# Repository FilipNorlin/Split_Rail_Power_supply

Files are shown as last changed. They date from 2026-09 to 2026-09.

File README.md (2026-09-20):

# PFC

# General Continuous-Time State-Space Form

$$
\dot{\mathbf{x}}(t) = A\mathbf{x}(t) + B\mathbf{u}(t)
$$
$$
\mathbf{y}(t) = C\mathbf{x}(t) + D\mathbf{u}(t)
$$

---

$$
	\underbrace{ \left(
		\begin{matrix}
		\dot{x}_{1}(t) \\
		\dot{x}_{2}(t) \\
		\dots \\
		\dot{x}_{n}(t)
		\end{matrix}
	\right) }_{ \dot{x}(t) }
	=
	\underbrace{ \left(
	\begin{matrix}
	A_{11}, A_{12} \dots A_{1n} \\
	A_{21}, A_{22} \dots A_{2n} \\
	\dots \\
	A_{n1}, A_{n2} \dots A_{nn}
	\end{matrix}
	\right) }_{ A }
	\underbrace{ \left(
	\begin{matrix}
	x_{1}(t) \\
	x_{2}(t) \\
	\dots \\
	x_{n}(t)
	\end{matrix}
	\right) }_{ x(t) }
	+ 
	\underbrace{ \left(
	\begin{matrix}
	B_{1} \\
	B_{2} \\
	\dots \\
	B_{n}
	\end{matrix}
	\right) }_{ B }	
	u(t)
$$

$$
y(t) = \underbrace{ [C_{1}, C_{2},\dots C_{n}] }_{ C } 
\underbrace{ \left(
\begin{matrix}
x_{1}(t) \\
x_{2}(t) \\
\dots \\
x_{n}(t)
\end{matrix}
\right) }_{ x(t) }
+
Du(t)
$$

# State Variables

## Large Signal Model

$$
\begin{align}
	x &= 
	\begin{bmatrix}
	i_{L_{A}}(t) \\
	i_{L_{B}}(t) \\
	v_{\text{out}}(t)
	\end{bmatrix}
	& \dot{x} = 
	\begin{bmatrix}
	\dot{i}_{L_{A}}(t) \\
	\dot{i}_{L_{B}}(t) \\
	\dot{v}_{\text{out}}(t)
	\end{bmatrix}
	&& u=v_{\text{in}}
	&& y=v_{\text{out}}
\end{align}
$$

The two switches are $180\degree$ out of phase. This means that the system will have 4 different states of operation. There will be a point where $\text{q}_{\text{A}}$ will be high and $\text{q}_{B}$ low and vise versa, if $\text{D}>0.5$ there will also be a point where both $\text{q}_{\text{A}}$ and $\text{q}_{B}$ will be high simultaneously. If $D < 0.5$  there will be a point where $\text{q}_{\text{A}}$ and $\text{q}_{\text{B}}$ both will be low simultaneously. This makes 4 states:

#### State 1: $\text{q}_{\text{A}}$ & $\text{q}_{\text{B}}$ are high

$$
\begin{align}
v_{L_{A}}(t) &= L \frac{di_{\text{L}_{A}}(t)}{dt} \implies \frac{di_{\text{L}_{A}}(t)}{dt} = \frac{v_{\text{in}}(t)}{L} \\ \\
v_{L_{B}}(t) &= L \frac{di_{\text{L}_{B}}(t)}{dt} \implies \frac{di_{\text{L}_{B}}(t)}{dt} = \frac{v_{\text{in}}(t)}{L} \\ \\
i_{c}(t) &= C \frac{d v_{c}(t)}{dt} \implies \frac{d v_{c}(t)}{dt} = \frac{i_{c}(t)}{C} = -\frac{v_{\text{out}}(t)}{RC}
\end{align}
$$

Both switches are turned on thus both inductors are getting magnetized. The capacitor isnt being charged at this point by any inductor meaning that it is only being discharged to the load, hence why the current is negative.

#### State 2: $\text{q}_{\text{A}}$ high & $\text{q}_{\text{B}}$ low

$$
\begin{align}
v_{L_{A}}(t) &= L \frac{di_{\text{L}_{A}}(t)}{dt} \implies \frac{di_{\text{L}_{A}}(t)}{dt} = \frac{v_{\text{in}}(t)}{L} \\ \\
v_{L_{B}}(t) &= L \frac{di_{\text{L}_{B}}(t)}{dt} \implies \frac{di_{\text{L}_{B}}(t)}{dt} = \frac{v_{\text{in}}(t) - v_{\text{out}}(t)}{L} \\ \\
i_{c}(t) &= C \frac{d v_{c}(t)}{dt} \implies \frac{d v_{c}(t)}{dt} = \frac{i_{c}(t)}{C} = \frac{i_{\text{L}_{B}}(t)}{C} -\frac{v_{\text{out}}(t)}{RC}
\end{align}
$$

Inductor A is still getting magnetized while inductor B is getting demagnetized. The energy from inductor B is being used to charge the output capacitor. 

#### State 3: $\text{q}_{\text{A}}$ low & $\text{q}_{\text{B}}$ high

$$
\begin{align}
v_{L_{A}}(t) &= L \frac{di_{\text{L}_{A}}(t)}{dt} \implies \frac{di_{\text{L}_{A}}(t)}{dt} = \frac{v_{\text{in}}(t) - v_{\text{out}}(t)}{L} \\ \\
v_{L_{B}}(t) &= L \frac{di_{\text{L}_{B}}(t)}{dt} \implies \frac{di_{\text{L}_{B}}(t)}{dt} = \frac{v_{\text{in}}(t)}{L} \\ \\
i_{c}(t) &= C \frac{d v_{c}(t)}{dt} \implies \frac{d v_{c}(t)}{dt} = \frac{i_{c}(t)}{C} = \frac{i_{\text{L}_{A}}(t)}{C} -\frac{v_{\text{out}}(t)}{RC}
\end{align}
$$

Now Inductor B is getting magnetized while inductor A is getting demagnetized. The energy from inductor A is being used to charge the output capacitor. 

#### State 4: $\text{q}_{\text{A}}$ low & $\text{q}_{\text{B}}$ low

$$
\begin{align}
v_{L_{A}}(t) &= L \frac{di_{\text{L}_{A}}(t)}{dt} \implies \frac{di_{\text{L}_{A}}(t)}{dt} = \frac{v_{\text{in}}(t) - v_{\text{out}}(t)}{L} \\ \\
v_{L_{B}}(t) &= L \frac{di_{\text{L}_{B}}(t)}{dt} \implies \frac{di_{\text{L}_{B}}(t)}{dt} = \frac{v_{\text{in}}(t) - v_{\text{out}}(t)}{L} \\ \\
i_{c}(t) &= C \frac{d v_{c}(t)}{dt} \implies \frac{d v_{c}(t)}{dt} = \frac{i_{c}(t)}{C} = \frac{i_{\text{L}_{A}}(t) + i_{\text{L}_{B}}(t)}{C} -\frac{v_{\text{out}}(t)}{RC}
\end{align}
$$

In this last state both the switches are off meaning that both the inductors are getting demagnetized into the capacitor. Having two or more inductors switching with some offset will make the capacitor get charged more frequently thus reducing the voltage ripple on the output. 

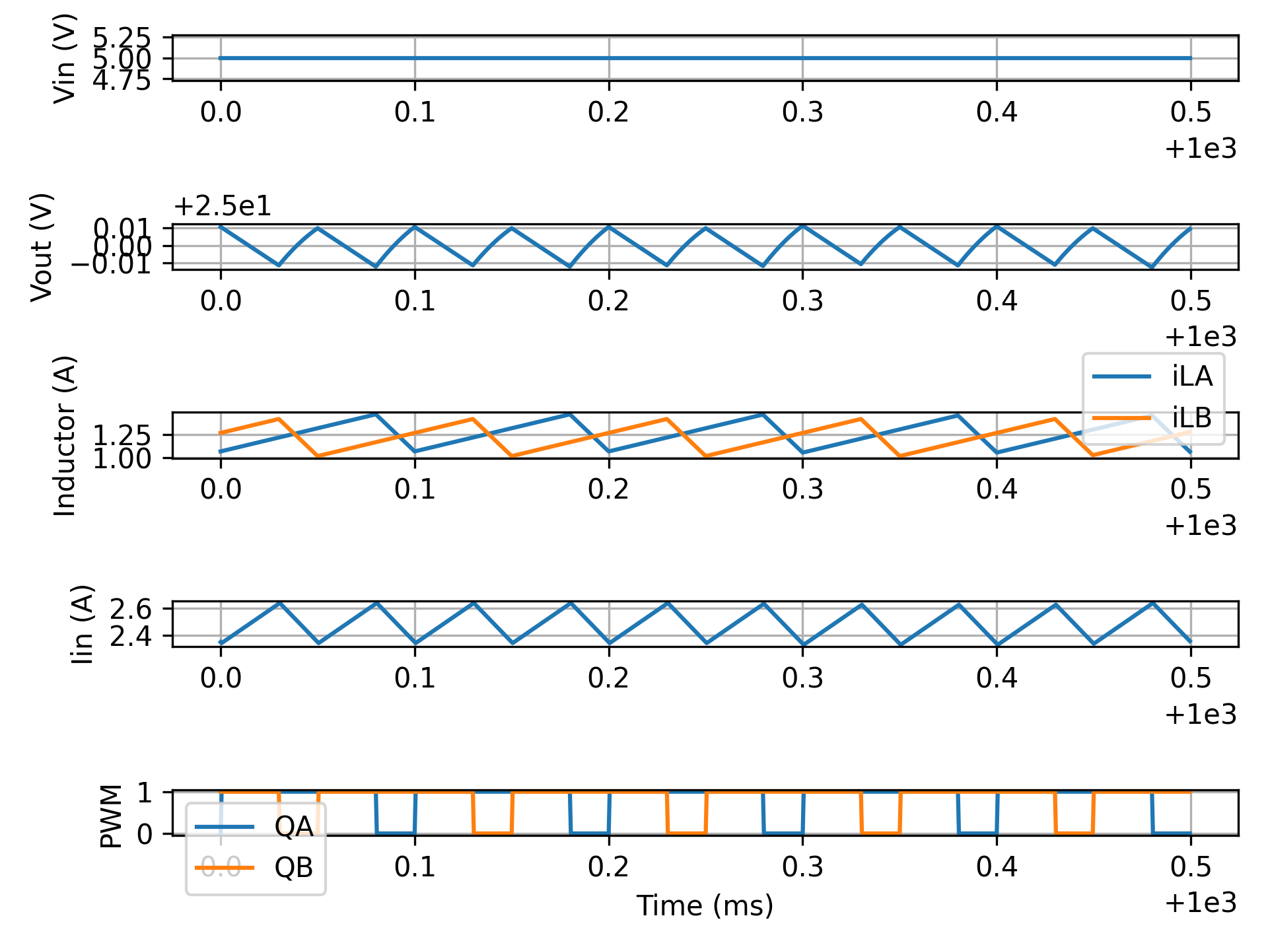
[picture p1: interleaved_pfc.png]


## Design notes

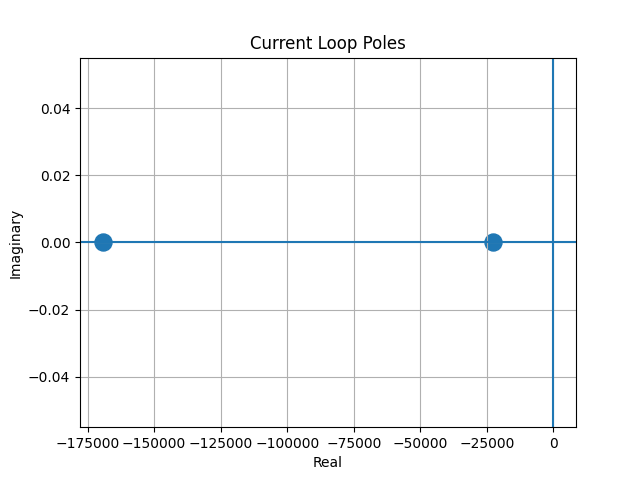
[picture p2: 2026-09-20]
Simulation/scirpts/dual_converter/Current_Loop_Poles.png

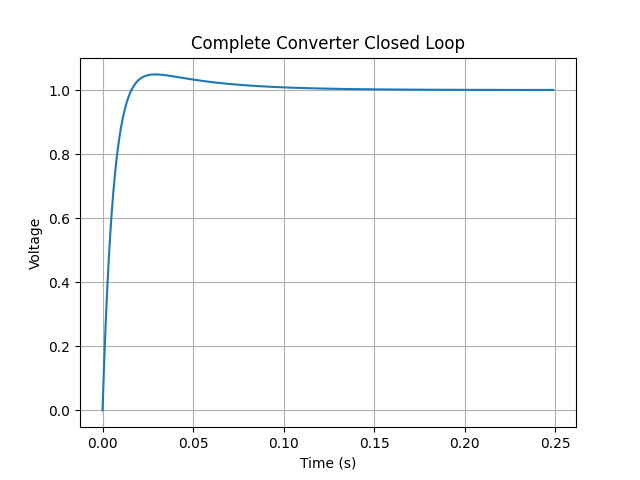
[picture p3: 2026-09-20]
Simulation/scirpts/dual_converter/Complete_Converter_Closed_Loop.png

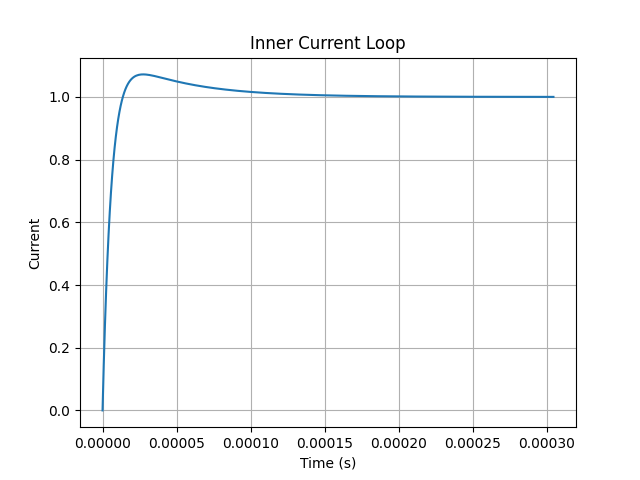
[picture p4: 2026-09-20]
Simulation/scirpts/dual_converter/Inner_Current_Loop.png

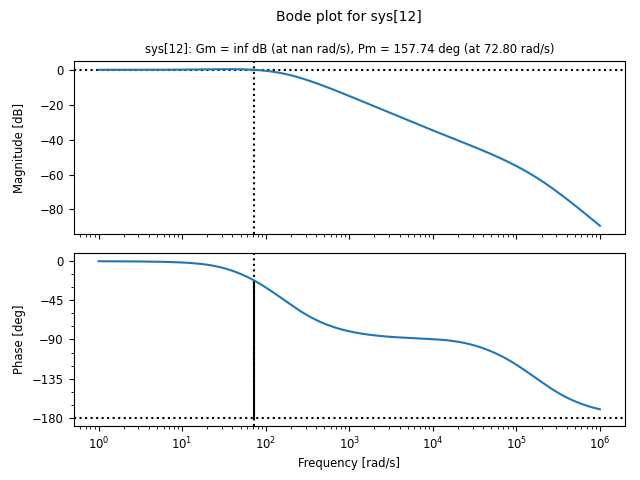
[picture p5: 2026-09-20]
Simulation/scirpts/dual_converter/Bode_plot.png

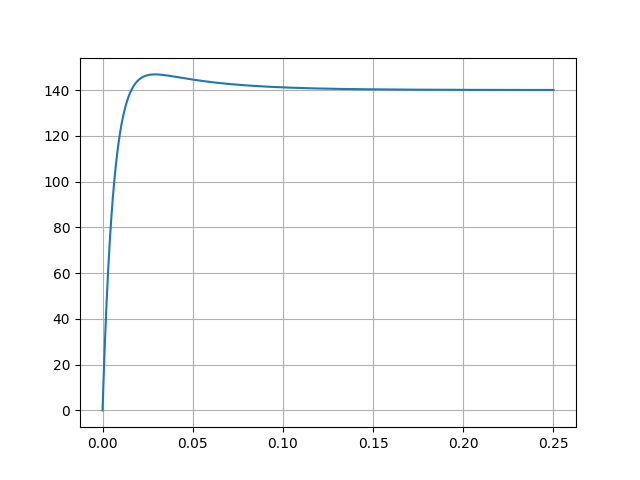
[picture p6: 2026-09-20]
Simulation/scirpts/dual_converter/Time_Domain.png

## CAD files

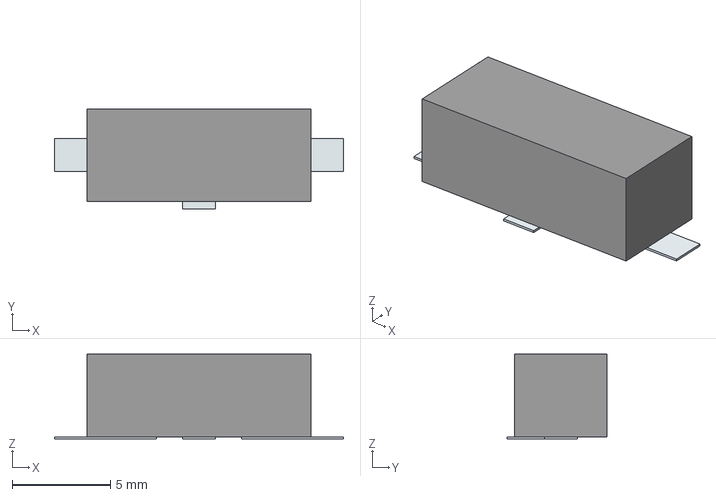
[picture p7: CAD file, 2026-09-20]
ECAD/Kicad_lib/3d-models/HC-49:US.stp
14.7 x 5.09 x 4.30 mm
Pins

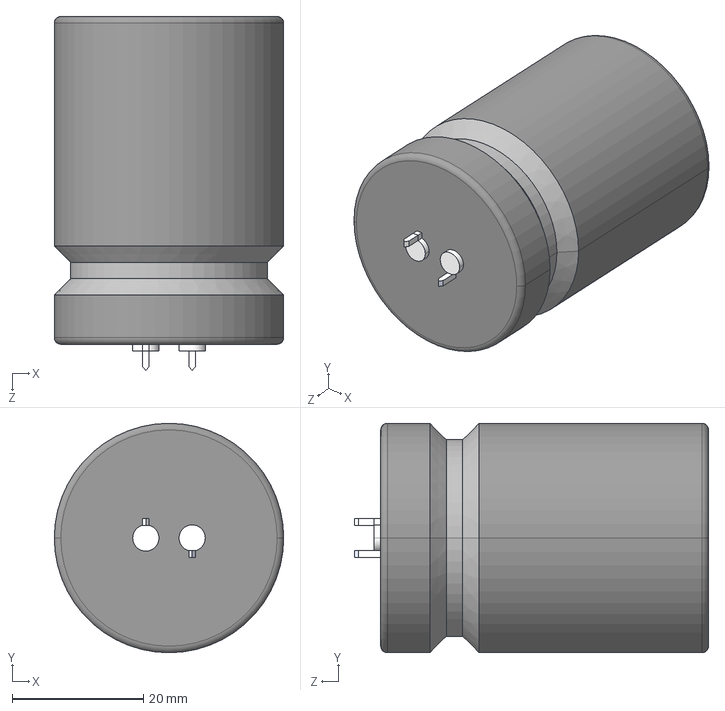
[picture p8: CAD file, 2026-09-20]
ECAD/Kicad_lib/3d-models/CP_Radial_D35.0mm_P10.00mm_SnapIn.stp
35.0 x 35.0 x 54.0 mm

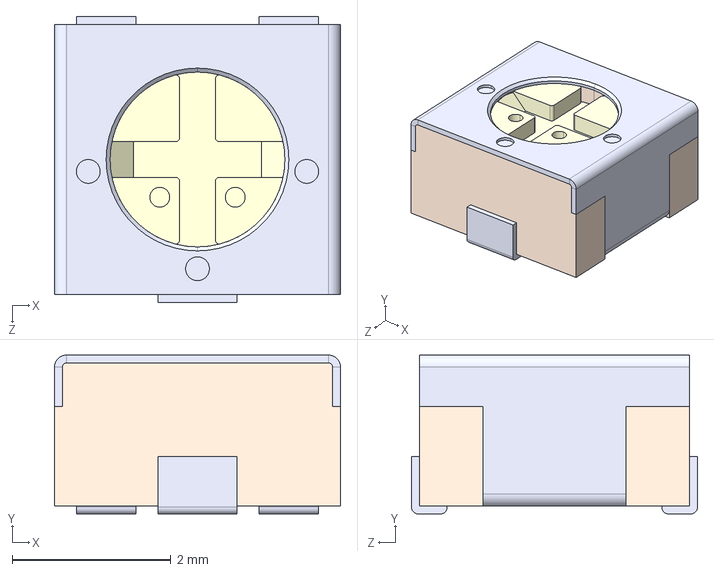
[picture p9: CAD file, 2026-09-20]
ECAD/Kicad_lib/3d-models/Potentiometer_SMD_Trimmer_PVG3_3.6x3.stp
3.60 x 2.00 x 3.60 mm

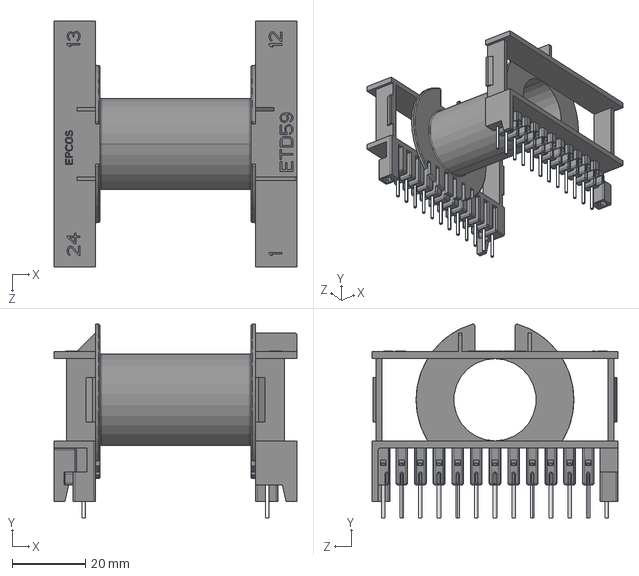
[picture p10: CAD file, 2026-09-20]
ECAD/Kicad_lib/3d-models/ETD59.stp
66.2 x 52.8 x 66.9 mm

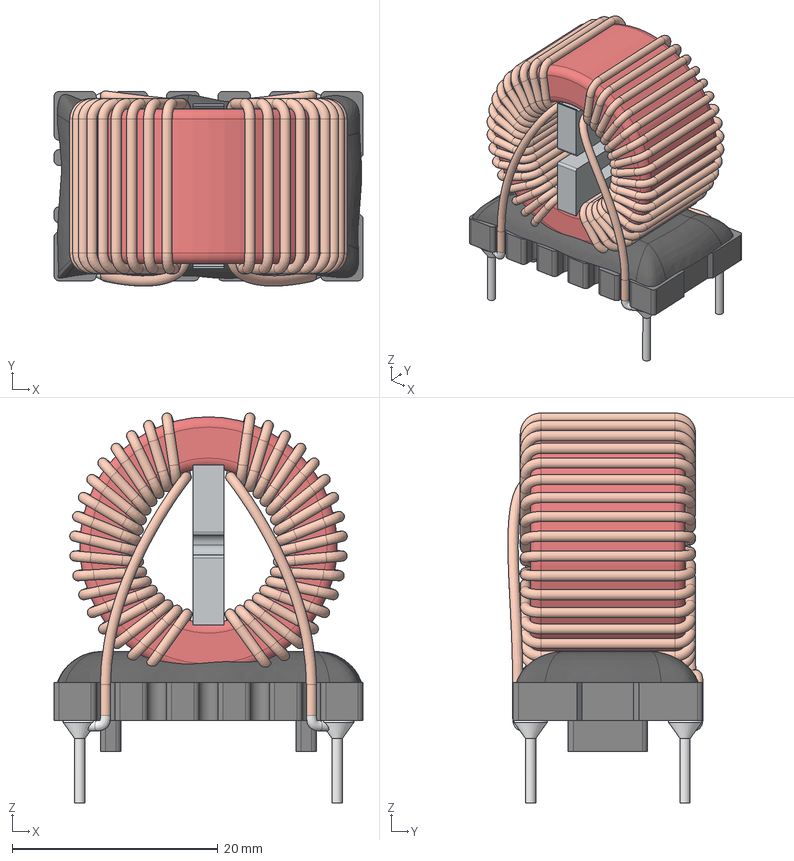
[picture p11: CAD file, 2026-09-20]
ECAD/Kicad_lib/3d-models/Common_Mode_Choke_2Line.stp
30.0 x 19.0 x 37.9 mm
Spacer
Glue
Solderpoint
Base

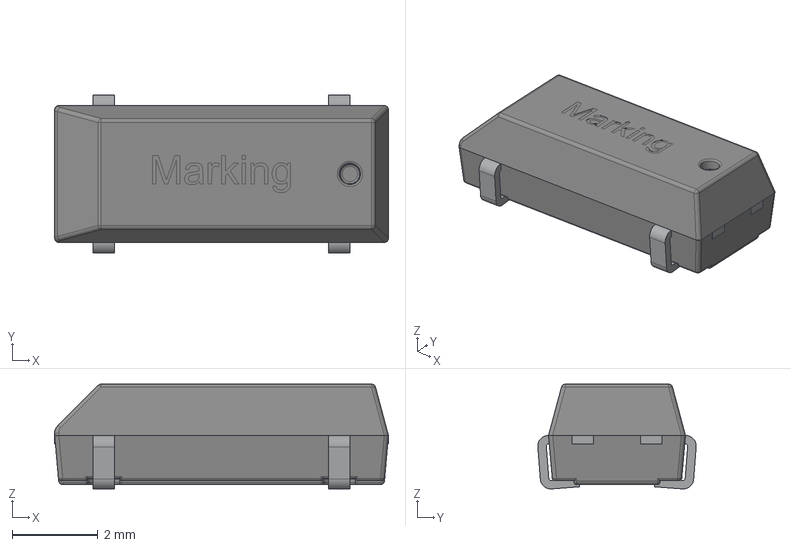
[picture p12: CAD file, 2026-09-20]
ECAD/Kicad_lib/3d-models/Crystal_SMD_8.7x3.8mm_P5.5mm_4Pad.stp
7.80 x 3.70 x 2.45 mm
Base
TopCover
Pin

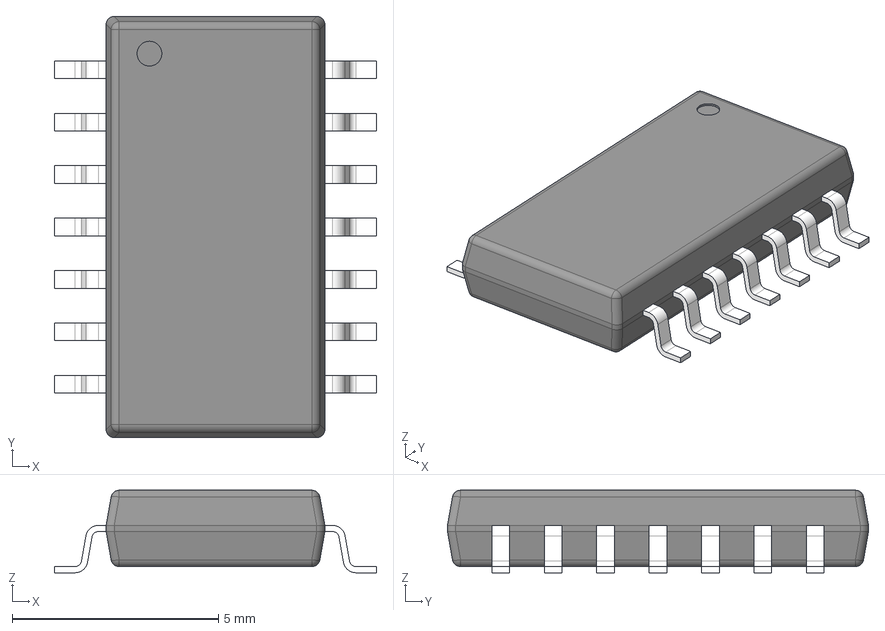
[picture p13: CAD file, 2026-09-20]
ECAD/Kicad_lib/3d-models/SN74HC132NSRG4.stp
7.80 x 10.2 x 2.00 mm
BODY-SO
LEAD-SO x 14

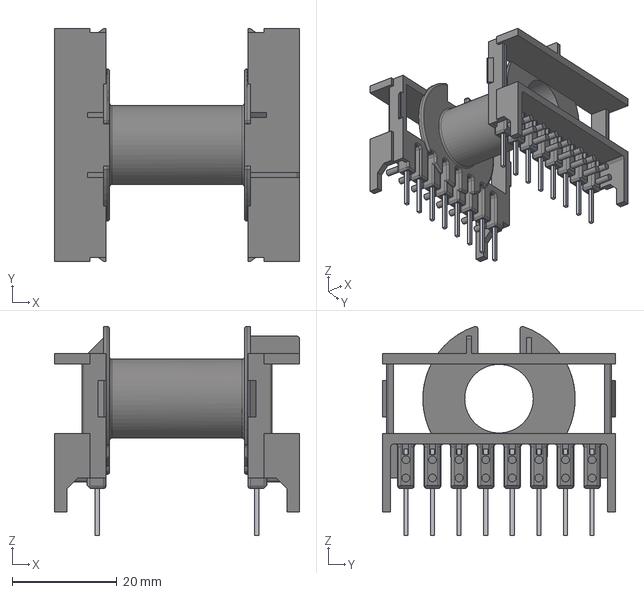
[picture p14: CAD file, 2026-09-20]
ECAD/Kicad_lib/3d-models/ETD39.stp
46.8 x 44.6 x 40.0 mm

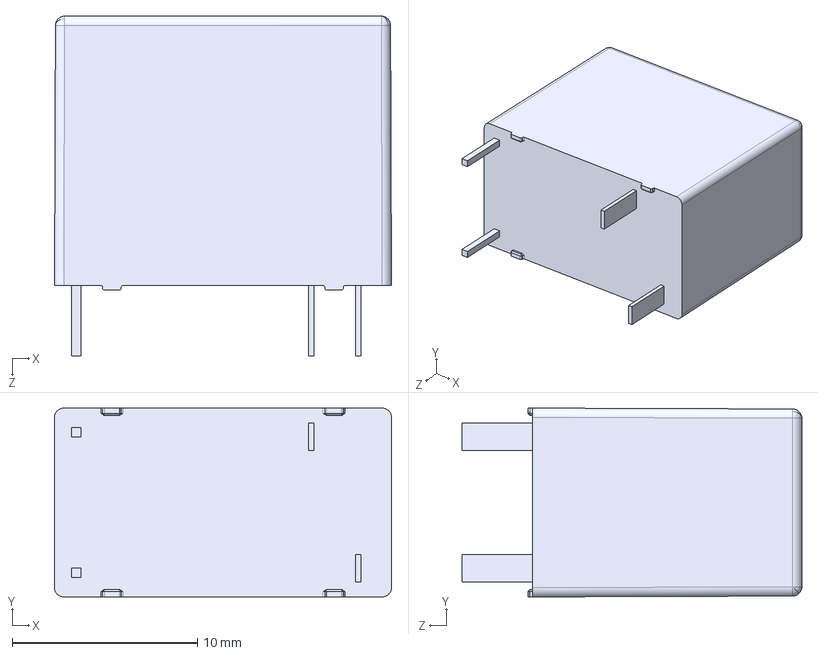
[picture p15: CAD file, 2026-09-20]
ECAD/Kicad_lib/3d-models/Industrial-Relays-OJS-SS-112HEF_SPST-NO.stp
18.2 x 10.2 x 18.4 mm

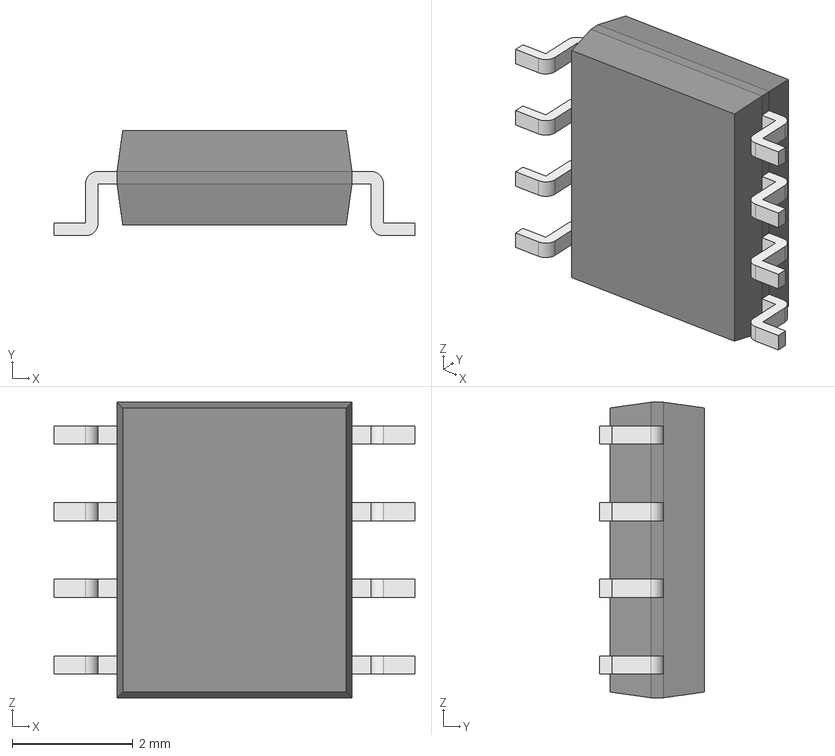
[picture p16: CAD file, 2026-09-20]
ECAD/Kicad_lib/3d-models/TL2843BDR-8.step
5.99 x 1.75 x 4.91 mm
Body001 (Mirror #1) x 4
XY-plane x 12
X-axis x 12

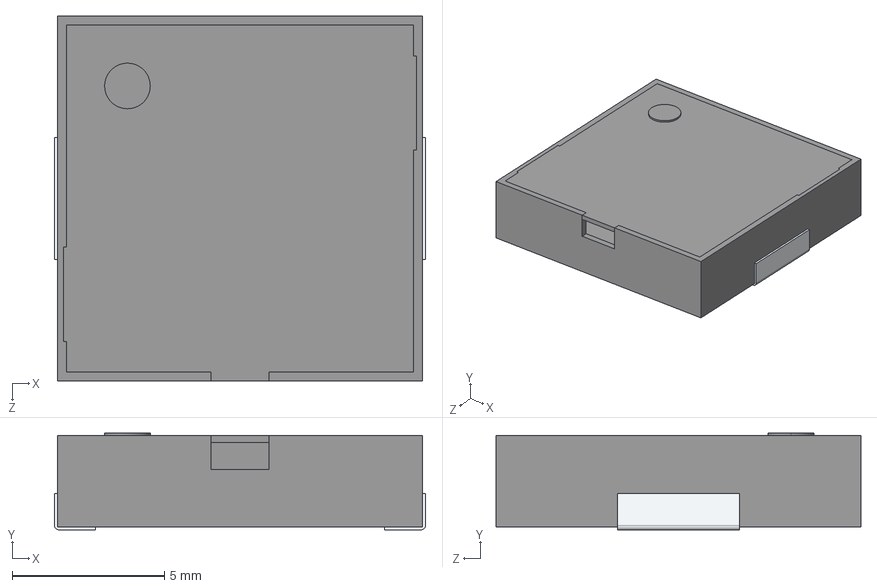
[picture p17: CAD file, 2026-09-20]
ECAD/Kicad_lib/3d-models/CPT-1203-78-SMT-TR.stp
12.2 x 3.18 x 12.0 mm

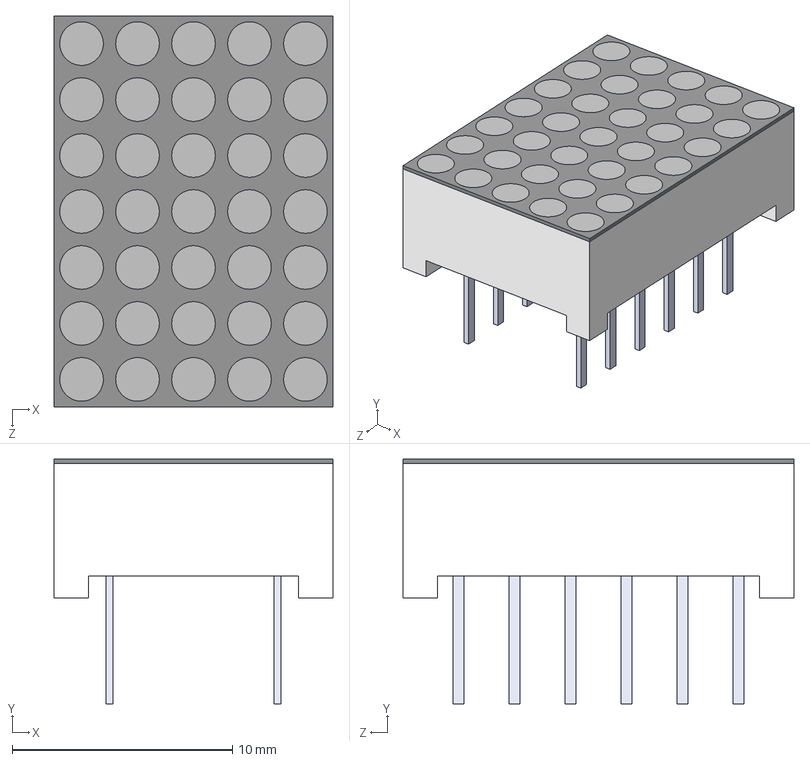
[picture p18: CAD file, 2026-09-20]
ECAD/Kicad_lib/3d-models/LTP-747KR.stp
12.7 x 11.1 x 17.7 mm

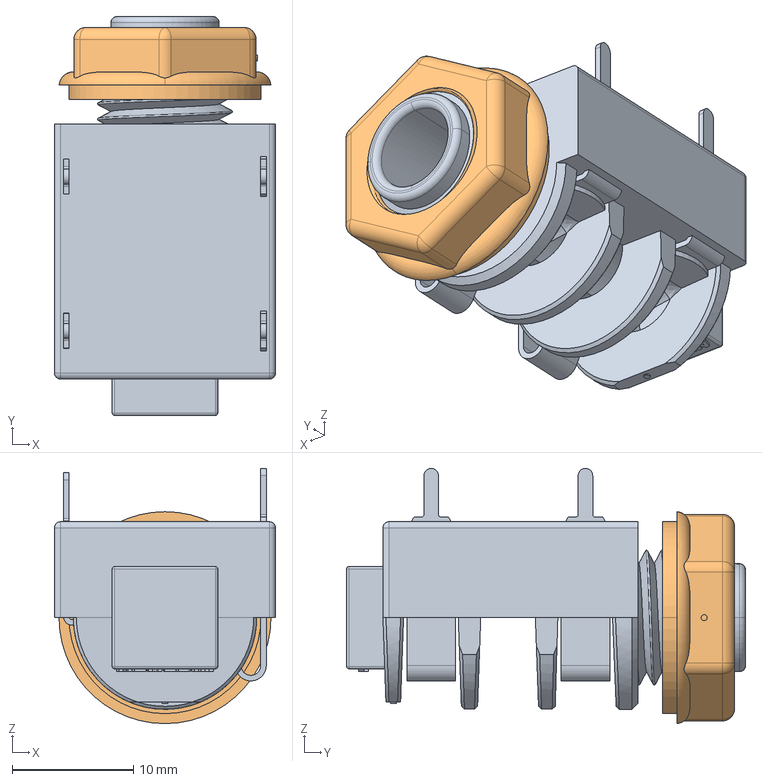
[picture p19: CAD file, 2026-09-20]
ECAD/Kicad_lib/3d-models/6.3mm_female_2-pol_mono_PCB.stp
18.2 x 32.9 x 21.0 mm

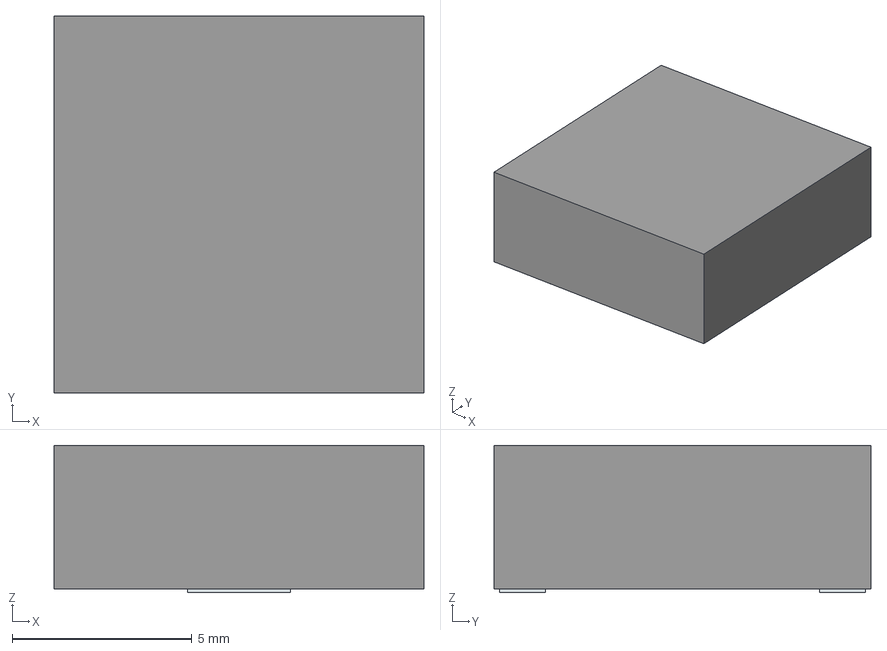
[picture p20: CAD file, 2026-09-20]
ECAD/Kicad_lib/3d-models/Inductor_SMD_Pulse_BPSC_10_5x10_3mm.stp
10.3 x 10.5 x 4.10 mm
Pins

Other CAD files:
ECAD/Kicad_lib/3d-models/TO-263-5.STEP
ECAD/Kicad_lib/3d-models/L_IHLP5050FD_5_0x5_0mm_Shielded.step
ECAD/Kicad_lib/3d-models/Heat_Sink_TO-220_25mm.step
ECAD/Kicad_lib/3d-models/10_segment_bar_graph.step
ECAD/Kicad_lib/3d-models/063932.stp
ECAD/Kicad_lib/3d-models/RCJ-013.STEP
ECAD/Kicad_lib/3d-models/Resistor_Axial_Power_WW20W_27mm.stp
ECAD/Kicad_lib/3d-models/TPS61175PWPR.step
ECAD/Kicad_lib/3d-models/TPS631000DRLR.stp

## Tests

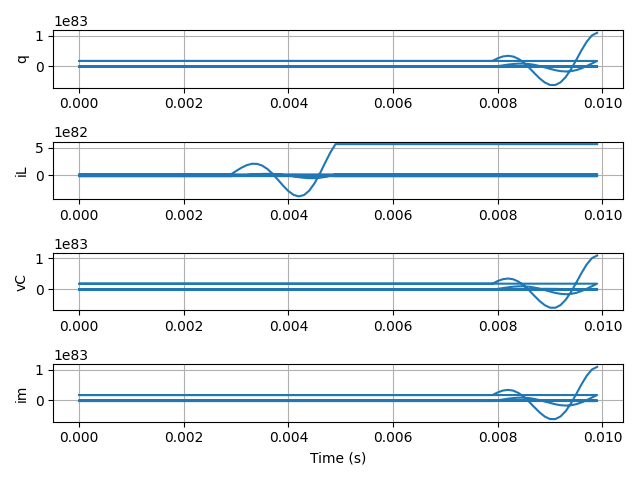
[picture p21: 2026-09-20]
Simulation/scirpts/test.png

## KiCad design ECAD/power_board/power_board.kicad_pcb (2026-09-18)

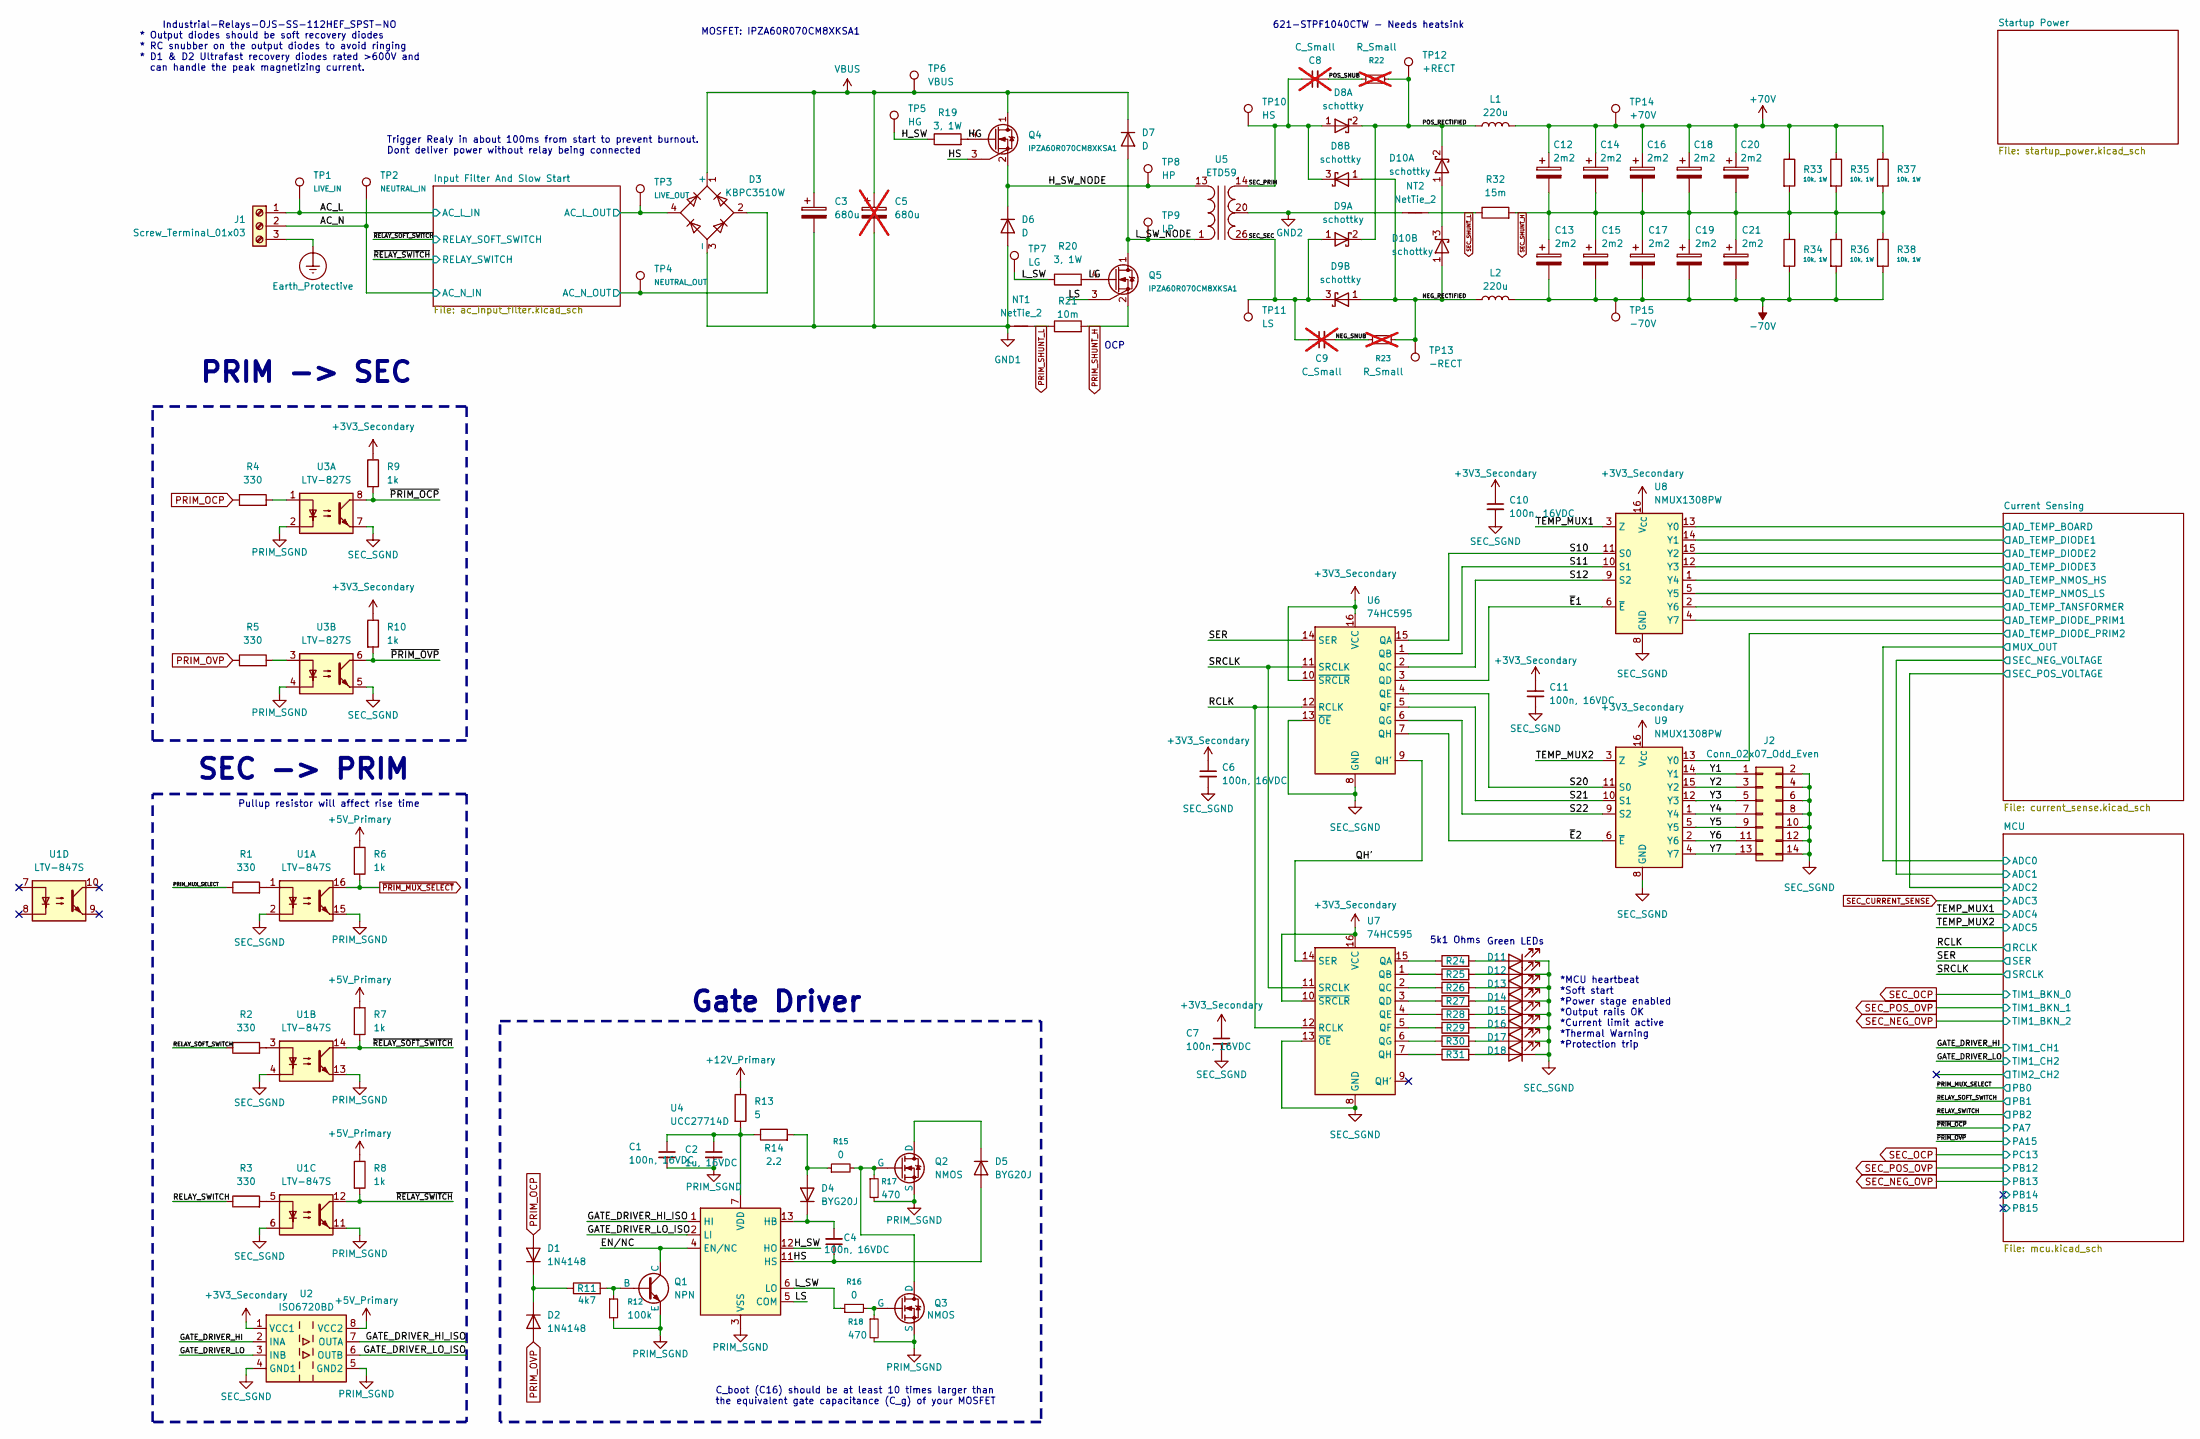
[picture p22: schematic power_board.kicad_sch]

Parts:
C1, C4, C6, C7, C10, C11: 100n, 16VDC; C_0805_2012Metric; Part-DB ID 9
C2: 1u, 16VDC; C_0805_2012Metric; Part-DB ID 36
C3: 680u; CP_Radial_D35.0mm_P10.00mm_SnapIn; Part-DB ID 53; Mouser No: 661-ESMQ451N681MA50S
C5: 680u; CP_Radial_D35.0mm_P10.00mm_SnapIn; Part-DB ID 53; Mouser No: 661-ESMQ451N681MA50S; not fitted
C8, C9: C_Small; C_1206_3216Metric; not fitted
C12, C13, C14, C15, C16, C17, C18, C19, C20, C21: 2m2; CP_Radial_D30.0mm_P10.00mm_SnapIn; Mouser No: 871-B41231C9228M060
D1, D2: 1N4148; D_DO-35_SOD27_P7.62mm_Horizontal
D3: KBPC3510W; Diode_Bridge_GeneSiC_KBPC_W; Part-DB ID 55; Mouser No: 905-KBPC3510W
D4, D5: BYG20J; D_SMA; Mouser No: 821-BYG20J
D6, D7: D; TO-220-2_Vertical; Mouser No: 755-RFN10TF6SFHC9
D8, D9, D10: schottky; TO-263-2; Mouser No: 78-VBT10202C-M3/4W
D11, D12, D13, D14, D15, D16, D17, D18: LED; LED_1206_3216Metric
J1: Screw_Terminal_01x03; TerminalBlock_Phoenix_MKDS-3-3-5.08_1x03_P5.08mm_Horizontal
J2: Conn_02x07_Odd_Even; PinHeader_2x07_P2.54mm_Vertical_SMD
L1, L2: 220u; ETD-39-Inductor
NT1, NT2: NetTie_2
Q1: NPN; SOT-23
Q2: NMOS; SOT-223-3_TabPin2; Mouser No: 755-R6004END4TL1
Q3: NMOS; SOT-23-3; Mouser No: 241-PJA3412_R1_00001
Q4: IPZA60R070CM8XKSA1; TO-247-4_Vertical; Part-DB ID 63
Q5: IPZA60R070CM8XKSA1; TO-247-4_Vertical
R1, R2, R3, R4, R5: 330; R_0805_2012Metric; Part-DB ID 68
R6, R7, R8, R9, R10: 1k; R_0805_2012Metric; Part-DB ID 66
R11: 4k7; R_0805_2012Metric
R12: 100k; R_0805_2012Metric
R13: 5; R_0805_2012Metric
R14: 2.2; R_1206_3216Metric; Mouser No: 652-CRM1206JW2R2ELF
R15, R16: 0; R_0603_1608Metric
R17, R18: 470; R_0805_2012Metric
R19, R20: 3, 1W; R_1206_3216Metric
R21: 10m; R_2512_6332Metric; Part-DB ID 32; Mouser No: 652-CFN0805-JZ-R010E
R22, R23: R_Small; R_1206_3216Metric; not fitted
R24, R25, R26, R27, R28, R29, R30, R31: 5k1; R_0805_2012Metric; Part-DB ID 17
R32: 15m; R_1206_3216Metric; Mouser No: 504-MFSA1206R0150FCM
R33, R34, R35, R36, R37, R38: 10k, 1W; R_2512_6332Metric; Mouser No: 279-CRGCQ2512J10K
TP1: LIVE_IN; Pin_D0.7mm_L6.5mm_W1.8mm_FlatFork
TP2: NEUTRAL_IN; Pin_D0.7mm_L6.5mm_W1.8mm_FlatFork
TP3: LIVE_OUT; Pin_D0.7mm_L6.5mm_W1.8mm_FlatFork
TP4: NEUTRAL_OUT; Pin_D0.7mm_L6.5mm_W1.8mm_FlatFork
TP5: HG; Pin_D0.7mm_L6.5mm_W1.8mm_FlatFork
TP6: VBUS; Pin_D0.7mm_L6.5mm_W1.8mm_FlatFork
TP7: LG; Pin_D0.7mm_L6.5mm_W1.8mm_FlatFork
TP8: HP; Pin_D0.7mm_L6.5mm_W1.8mm_FlatFork
TP9: LP; Pin_D0.7mm_L6.5mm_W1.8mm_FlatFork
TP10: HS; Pin_D0.7mm_L6.5mm_W1.8mm_FlatFork
TP11: LS; Pin_D0.7mm_L6.5mm_W1.8mm_FlatFork
TP12: +RECT; Pin_D0.7mm_L6.5mm_W1.8mm_FlatFork
TP13: -RECT; Pin_D0.7mm_L6.5mm_W1.8mm_FlatFork
TP14: +70V; Pin_D0.7mm_L6.5mm_W1.8mm_FlatFork
TP15: -70V; Pin_D0.7mm_L6.5mm_W1.8mm_FlatFork
U1: LTV-847S; SMDIP-16_W9.53mm; Mouser No: 859-LTV-847S-BC
U2: ISO6720BD; SOIC-8_3.9x4.9mm_P1.27mm; Mouser No: 595-ISO6720BDR
U3: LTV-827S; SMDIP-8_W9.53mm; Mouser No: 859-LTV-827S
U4: UCC27714D; SOIC-14_3.9x8.7mm_P1.27mm; Part-DB ID 60; Mouser No: 595-UCC27714DR
U5: ETD59
U6, U7: 74HC595; SOIC-16_3.9x9.9mm_P1.27mm; Part-DB ID 81
U8, U9: NMUX1308PW; TSSOP-16_4.4x5mm_P0.65mm; Mouser No: 771-NMUX1308PW-Q100J

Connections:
+3V3_Secondary: C6.1, C7.1, C10.1, C11.1, R9.1, R10.1, U2.1 (VCC1), U6.10 (~SRCLR), U6.16 (VCC), U7.10 (~SRCLR), U7.16 (VCC), U8.16 (V_{CC}), U9.16 (V_{CC}); also elsewhere on the board
+5V_Primary: R6.1, R7.1, R8.1, U2.8 (VCC2); also elsewhere on the board
+12V_Primary: R13.1; also elsewhere on the board
+70V: C12.1, C14.1, C16.1, C18.1, C20.1, L1.2, R33.1, R35.1, R37.1, TP14.1 (1_1); also elsewhere on the board
-70V: C13.2, C15.2, C17.2, C19.2, C21.2, L2.2, R34.2, R36.2, R38.2, TP15.1 (1_1); also elsewhere on the board
/AC_L: J1.1, TP1.1 (1_1); also elsewhere on the board
/AC_N: J1.2, TP2.1 (1_1); also elsewhere on the board
/Current Sensing/AD_TEMP_BOARD: U8.13 (Y0); also elsewhere on the board
/Current Sensing/AD_TEMP_DIODE1: U8.14 (Y1); also elsewhere on the board
/Current Sensing/AD_TEMP_DIODE2: U8.15 (Y2); also elsewhere on the board
/Current Sensing/AD_TEMP_DIODE3: U8.12 (Y3); also elsewhere on the board
/Current Sensing/AD_TEMP_DIODE_PRIM1: U8.4 (Y7); also elsewhere on the board
/Current Sensing/AD_TEMP_DIODE_PRIM2: U9.13 (Y0); also elsewhere on the board
/Current Sensing/AD_TEMP_NMOS_HS: U8.1 (Y4); also elsewhere on the board
/Current Sensing/AD_TEMP_NMOS_LS: U8.5 (Y5); also elsewhere on the board
/Current Sensing/AD_TEMP_TANSFORMER: U8.2 (Y6); also elsewhere on the board
/EN/NC: Q1.1 (C), U4.4 (EN/NC)
/GATE_DRIVER_HI: U2.2 (INA); also elsewhere on the board
/GATE_DRIVER_HI_ISO: U2.7 (OUTA), U4.1 (HI)
/GATE_DRIVER_LO: U2.3 (INB); also elsewhere on the board
/GATE_DRIVER_LO_ISO: U2.6 (OUTB), U4.2 (LI)
/HG: Q4.4 (G), R19.2
/HS: C4.1, D5.2 (A), Q4.3 (DS), U4.11 (HS)
/H_SW: R19.1, TP5.1 (1_1), U4.12 (HO)
/H_SW_NODE: D6.1 (K), Q4.2 (S), TP8.1 (1_1), U5.13 (P1)
/Input Filter And Slow Start/AC_L_OUT: D3.4, TP3.1 (1_1); also elsewhere on the board
/Input Filter And Slow Start/AC_N_OUT: D3.2, TP4.1 (1_1); also elsewhere on the board
/LG: Q5.4 (G), R20.2
/LS: Q5.3 (DS), U4.5 (COM)
/L_SW: R16.1, R20.1, TP7.1 (1_1), U4.6 (LO)
/L_SW_NODE: D7.2 (A), Q5.1 (D), TP9.1 (1_1), U5.1 (P2)
/NEG_SNUB: C9.2, R23.1
/POS_RECTIFIED: D8.2 (K), D9.2 (K), D10.2 (K), L1.1, R22.2, TP12.1 (1_1), U5.9
/POS_SNUB: C8.2, R22.1, U5.24
/PRIM_MUX_SELECT: R1.1; also elsewhere on the board
/QH': U6.9 (QH'), U7.14 (SER)
/RCLK: U6.12 (RCLK), U7.12 (RCLK); also elsewhere on the board
/RELAY_SOFT_SWITCH: R2.1; also elsewhere on the board
/RELAY_SWITCH: R3.1; also elsewhere on the board
/S10: U6.15 (QA), U8.11 (S0)
/S11: U6.1 (QB), U8.10 (S1)
/S12: U6.2 (QC), U8.9 (S2)
/S20: U6.4 (QE), U9.11 (S0)
/S21: U6.5 (QF), U9.10 (S1)
/S22: U6.6 (QG), U9.9 (S2)
/SER: U6.14 (SER); also elsewhere on the board
/SRCLK: U6.11 (SRCLK), U7.11 (SRCLK); also elsewhere on the board
/TEMP_MUX1: U8.3 (Z); also elsewhere on the board
/TEMP_MUX2: U9.3 (Z); also elsewhere on the board
/Y1: J2.1, U9.14 (Y1)
/Y2: J2.3, U9.15 (Y2)
/Y3: J2.5, U9.12 (Y3)
/Y4: J2.7, U9.1 (Y4)
/Y5: J2.9, U9.5 (Y5)
/Y6: J2.11, U9.2 (Y6)
/Y7: J2.13, U9.4 (Y7)
/~E1: U6.3 (QD), U8.6 (~E)
/~E2: U6.7 (QH), U9.6 (~E)
/~PRIM_OCP: R9.2, U3.8; also elsewhere on the board
/~PRIM_OVP: R10.2, U3.6; also elsewhere on the board
/~RELAY_SOFT_SWITCH: R7.2, U1.14; also elsewhere on the board
/~RELAY_SWITCH: R8.2, U1.12; also elsewhere on the board
Earth_Protective: J1.3; also elsewhere on the board
GND1: C3.2, C5.2, D3.3 (-), D6.2 (A), NT1.2; also elsewhere on the board
GND2: NT2.1, U5.20 (SC)
unnamed: D1.1 (K), D2.1 (K), R11.1
unnamed: D4.2 (A), R14.2, R15.1
unnamed: C4.2, D4.1 (K), U4.13 (HB)
unnamed: D5.1 (K), Q2.1 (D)
unnamed: D11.2 (A), R24.2
unnamed: D12.2 (A), R25.2
unnamed: D13.2 (A), R26.2
unnamed: D14.2 (A), R27.2
unnamed: D15.2 (A), R28.2
unnamed: D16.2 (A), R29.2
unnamed: D17.2 (A), R30.2
unnamed: D18.2 (A), R31.2
unnamed: Q1.2 (B), R11.2, R12.1
unnamed: Q2.2 (G), Q3.1 (D), R15.2, R17.1
unnamed: Q3.2 (G), R16.2, R18.1
unnamed: R1.2, U1.1
unnamed: R2.2, U1.3
unnamed: R3.2, U1.5
unnamed: R4.2, U3.1
unnamed: R5.2, U3.3
unnamed: C1.1, C2.1, R13.2, R14.1, U4.7 (VDD)
unnamed: R24.1, U7.15 (QA)
unnamed: R25.1, U7.1 (QB)
unnamed: R26.1, U7.2 (QC)
unnamed: R27.1, U7.3 (QD)
unnamed: R28.1, U7.4 (QE)
unnamed: R29.1, U7.5 (QF)
unnamed: R30.1, U7.6 (QG)
unnamed: R31.1, U7.7 (QH)
PRIM_OCP: D1.2 (A), R4.1; also elsewhere on the board
PRIM_OVP: D2.2 (A), R5.1; also elsewhere on the board
PRIM_SGND: C1.2, C2.2, Q1.3 (E), Q2.3 (S), Q3.3 (S), R12.2, R17.2, R18.2, U1.11, U1.13, U1.15, U2.5 (GND2), U3.2, U3.4, U4.3 (VSS); also elsewhere on the board
PRIM_SHUNT_H: Q5.2 (S), R21.2; also elsewhere on the board
PRIM_SHUNT_L: NT1.1, R21.1; also elsewhere on the board
SEC_SGND: C6.2, C7.2, C10.2, C11.2, D11.1 (K), D12.1 (K), D13.1 (K), D14.1 (K), D15.1 (K), D16.1 (K), D17.1 (K), D18.1 (K), J2.2, J2.4, J2.6, J2.8, J2.10, J2.12, J2.14, U1.2, U1.4, U1.6, U2.4 (GND1), U3.5, U3.7, U6.8 (GND), U6.13 (~OE), U7.8 (GND), U7.13 (~OE), U8.8 (GND), U9.8 (GND); also elsewhere on the board
SEC_SHUNT_H: C12.2, C13.1, C14.2, C15.1, C16.2, C17.1, C18.2, C19.1, C20.2, C21.1, R32.2, R33.2, R34.1, R35.2, R36.1, R37.2, R38.1; also elsewhere on the board
SEC_SHUNT_L: NT2.2, R32.1; also elsewhere on the board
VBUS: C3.1, C5.1, D3.1 (+), D7.1 (K), Q4.1 (D), TP6.1 (1_1); also elsewhere on the board
~PRIM_MUX_SELECT: R6.2, U1.16

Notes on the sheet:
Pullup resistor will affect rise time
621-STPF1040CTW - Needs heatsink
Trigger Realy in about 100ms from start to prevent burnout. Dont deliver power without relay being connected
MOSFET: IPZA60R070CM8XKSA1
* Output diodes should be soft recovery diodes * RC snubber on the output diodes to avoid ringing * D1 & D2 Ultrafast recovery diodes rated >600V and can handle the peak magnetizing current.
SEC -> PRIM
Industrial-Relays-OJS-SS-112HEF_SPST-NO
C_boot (C16) should be at least 10 times larger than the equivalent gate capacitance (C_g) of your MOSFET
OCP
5k1 Ohms
Gate Driver
Green LEDs
PRIM -> SEC
*MCU heartbeat *Soft start *Power stage enabled *Output rails OK *Current limit active *Thermal Warning *Protection trip

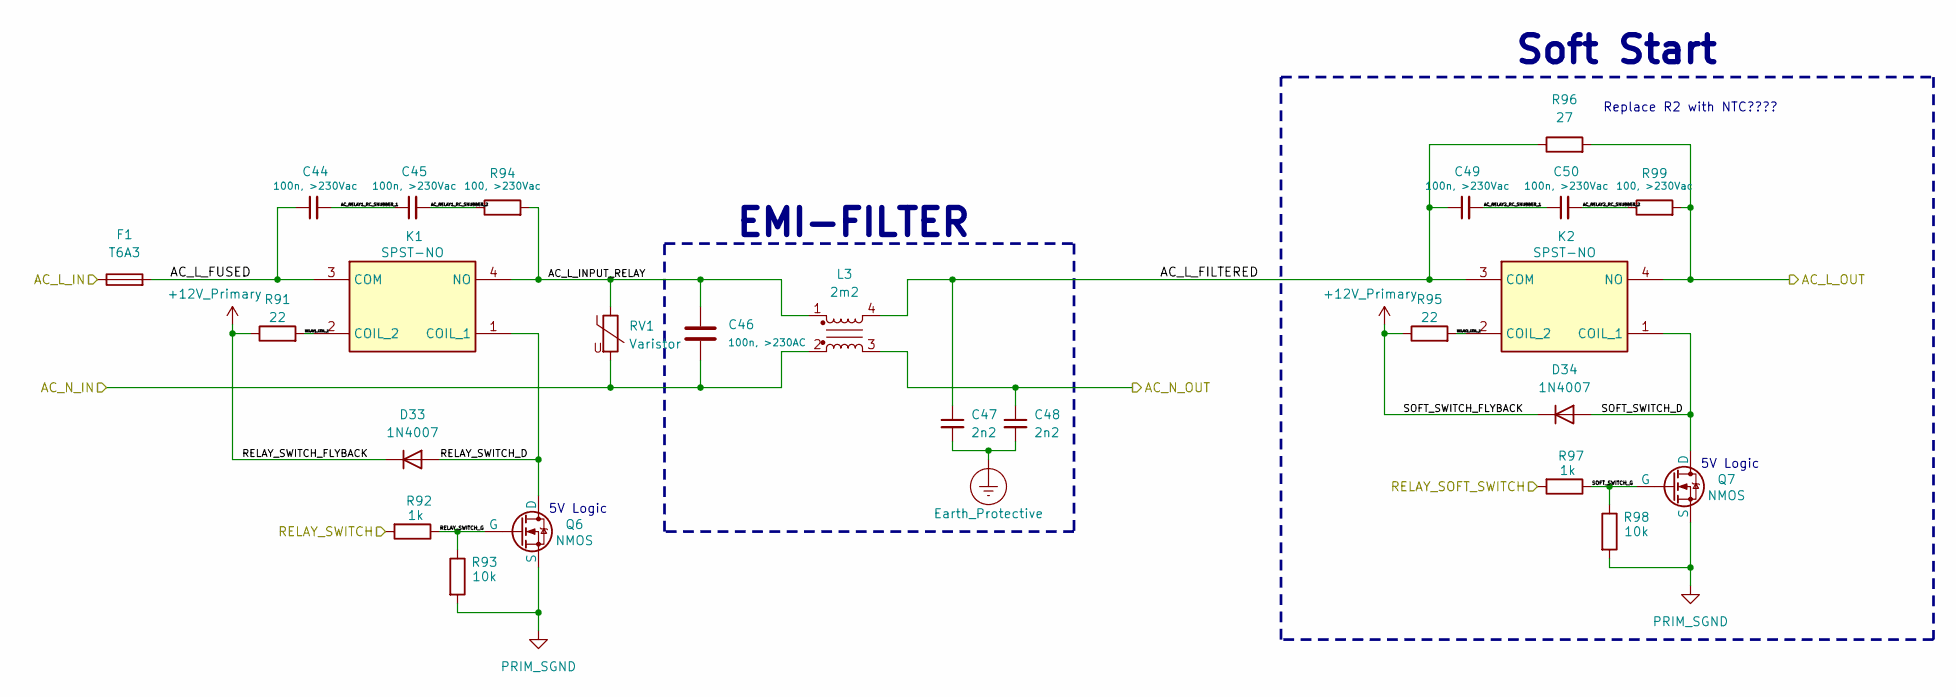
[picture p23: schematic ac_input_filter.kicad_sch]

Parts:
C44, C45, C49, C50: 100n, >230Vac; C_Rect_L13.0mm_W5.0mm_P10.00mm_FKS3_FKP3_MKS4; Mouser No: 710-890324023023
C46: 100n, >230AC; C_Rect_L18.0mm_W6.0mm_P15.00mm_FKS3_FKP3; Mouser No: 505-MKX2AW31004CMSSD
C47: 2n2; C_Rect_L18.0mm_W6.0mm_P15.00mm_FKS3_FKP3; Part-DB ID 59; Mouser No: 594-F340Y232230MFP2B
C48: 2n2; C_Rect_L18.0mm_W6.0mm_P15.00mm_FKS3_FKP3; Mouser No: 594-F340Y232230MFP2B
D33, D34: 1N4007; D_DO-41_SOD81_P10.16mm_Horizontal
F1: T6A3; Fuseholder_Clip-5x20mm_Keystone_3512_Inline_P23.62x7.27mm_D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
K1, K2: SPST-NO; Industrial-Relays-OJS-SS-112HEF_SPST-NO; Mouser Part Number 655-2071556-1
L3: 2m2; Common_Mode_Choke_2Line; Mouser Part Number 710-7448258022
Q6, Q7: NMOS; SOT-23-3; Mouser No: 241-PJA3412_R1_00001
R91, R95: 22; R_1206_3216Metric
R92, R97: 1k; R_0805_2012Metric; Part-DB ID 66
R93, R98: 10k; R_0805_2012Metric; Part-DB ID 67
R94, R99: 100, >230Vac; R_Axial_DIN0411_L9.9mm_D3.6mm_P12.70mm_Horizontal; Mouser No: 603-CFR-50JR-52-100R
R96: 27; Resistor_THT_Power_Axial_WW20W_P27mm; Part-DB ID 58; Mouser No: 588-TWW20J27RE
RV1: Varistor; RV_Disc_D15.5mm_W5mm_P7.5mm; Mouser No: 603-431KH14-AT

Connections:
+12V_Primary: D33.1 (K), D34.1 (K), R91.1, R95.1; also elsewhere on the board
/AC_L: F1.1; also elsewhere on the board
/AC_N: C46.2, L3.2, RV1.2; also elsewhere on the board
/Input Filter And Slow Start/AC_L_FILTERED: C47.1, C49.1, K2.3 (COM), L3.4, R96.1
/Input Filter And Slow Start/AC_L_FUSED: C44.1, F1.2, K1.3 (COM)
/Input Filter And Slow Start/AC_L_INPUT_RELAY: C46.1, K1.4 (NO), L3.1, R94.2, RV1.1
/Input Filter And Slow Start/AC_L_OUT: K2.4 (NO), R96.2, R99.2; also elsewhere on the board
/Input Filter And Slow Start/AC_N_OUT: C48.1, L3.3; also elsewhere on the board
/Input Filter And Slow Start/AC_RELAY1_RC_SNUBBER_1: C44.2, C45.1
/Input Filter And Slow Start/AC_RELAY1_RC_SNUBBER_2: C45.2, R94.1
/Input Filter And Slow Start/AC_RELAY2_RC_SNUBBER_1: C49.2, C50.1
/Input Filter And Slow Start/AC_RELAY2_RC_SNUBBER_2: C50.2, R99.1
/Input Filter And Slow Start/RELAY1_COIL_2: K1.2 (COIL_2), R91.2
/Input Filter And Slow Start/RELAY2_COIL_2: K2.2 (COIL_2), R95.2
/Input Filter And Slow Start/RELAY_SWITCH_D: D33.2 (A), K1.1 (COIL_1), Q6.1 (D)
/Input Filter And Slow Start/RELAY_SWITCH_G: Q6.2 (G), R92.1, R93.1
/Input Filter And Slow Start/SOFT_SWITCH_D: D34.2 (A), K2.1 (COIL_1), Q7.1 (D)
/Input Filter And Slow Start/SOFT_SWITCH_G: Q7.2 (G), R97.1, R98.1
/~RELAY_SOFT_SWITCH: R97.2; also elsewhere on the board
/~RELAY_SWITCH: R92.2; also elsewhere on the board
Earth_Protective: C47.2, C48.2; also elsewhere on the board
PRIM_SGND: Q6.3 (S), Q7.3 (S), R93.2, R98.2; also elsewhere on the board

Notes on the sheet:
Replace R2 with NTC????
5V Logic
Soft Start
EMI-FILTER

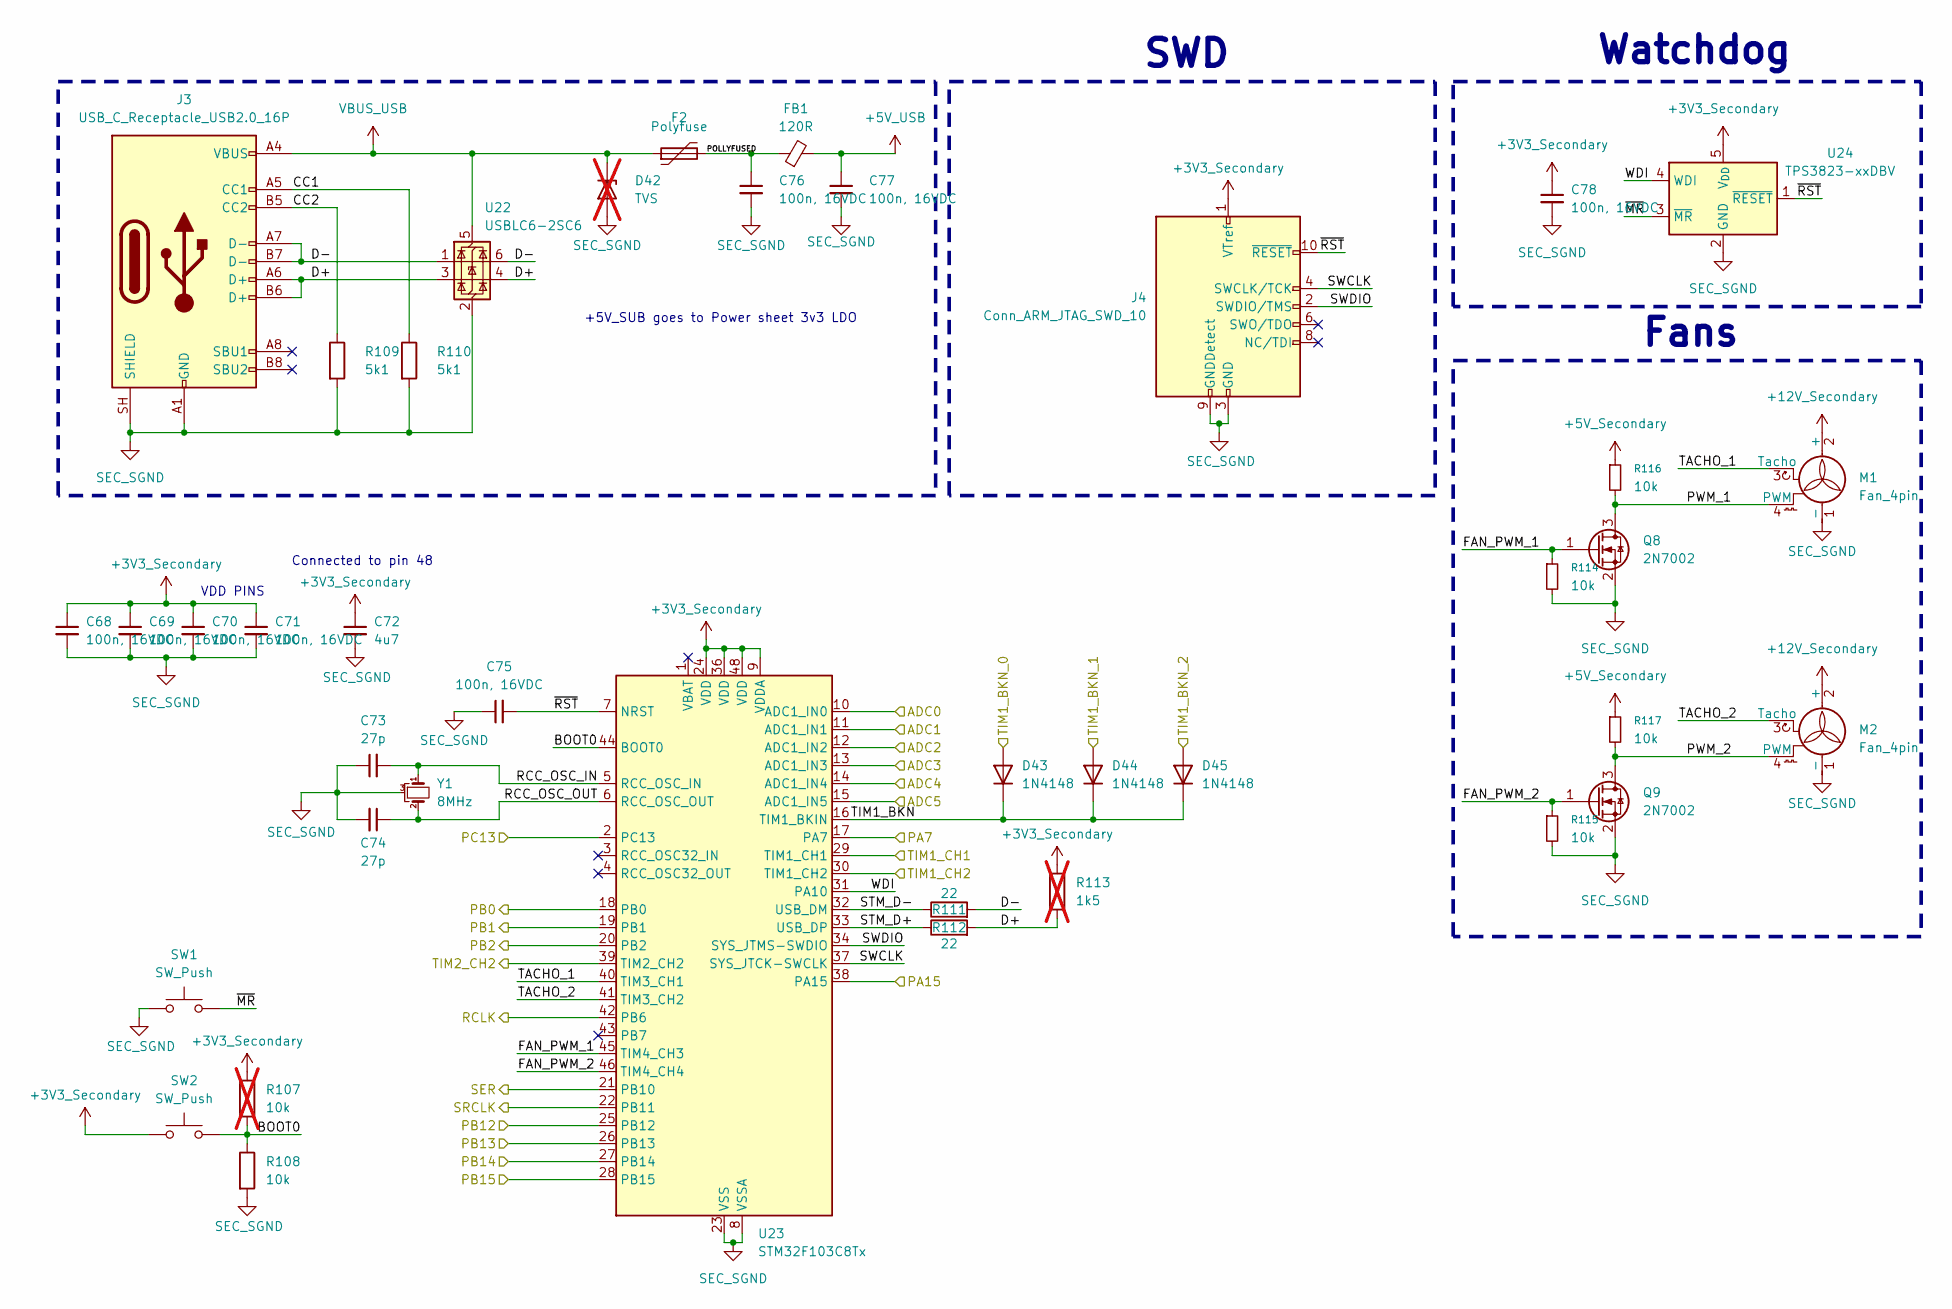
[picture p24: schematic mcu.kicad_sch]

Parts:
C68, C69, C70, C71, C75, C76, C77, C78: 100n, 16VDC; C_0805_2012Metric; Part-DB ID 9
C72: 4u7; C_0805_2012Metric
C73, C74: 27p; C_0603_1608Metric
D42: TVS; D_SOD-523; Mouser No: 637-ESD5B5V0WT; not fitted
D43, D44, D45: 1N4148; D_DO-35_SOD27_P7.62mm_Horizontal
F2: Polyfuse; RV_Disc_D15.5mm_W5mm_P7.5mm; Mouser No: 576-60R050XU
FB1: 120R; L_0805_2012Metric
J3: USB_C_Receptacle_USB2.0_16P; USB_C_Receptacle_GCT_USB4105-xx-A_16P_TopMnt_Horizontal; Part-DB ID 82
J4: Conn_ARM_JTAG_SWD_10; PinHeader_2x05_P1.27mm_Vertical_SMD
M1, M2: Fan_4pin; FanPinHeader_1x04_P2.54mm_Vertical
Q8, Q9: 2N7002; SOT-23
R107: 10k; R_0805_2012Metric; not fitted
R108, R114, R115, R116, R117: 10k; R_0805_2012Metric; Part-DB ID 67
R109, R110: 5k1; R_0805_2012Metric; Part-DB ID 17
R111, R112: 22; R_0603_1608Metric
R113: 1k5; R_0603_1608Metric; not fitted
SW1, SW2: SW_Push; SW_Push_1P1T_NO_CK_KSC6xxJ
U22: USBLC6-2SC6; SOT-23-6
U23: STM32F103C8Tx; LQFP-48_7x7mm_P0.5mm; Part-DB ID 29
U24: TPS3823-xxDBV; SOT-23-5; Mouser No: 595-TPS3823-25DBVR
Y1: 8MHz; HC-49US; Mouser No: 815-ABLSG-8-D2YT

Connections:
+3V3_Secondary: C68.1, C69.1, C70.1, C71.1, C72.1, C78.1, J4.1 (VTref), R107.1, R113.1, SW2.1, U23.9 (VDDA), U23.24 (VDD), U23.36 (VDD), U23.48 (VDD), U24.5 (V_{DD}); also elsewhere on the board
+5V_Secondary: R116.1, R117.1; also elsewhere on the board
+5V_USB: C77.1, FB1.2; also elsewhere on the board
+12V_Secondary: M1.2 (+), M2.2 (+); also elsewhere on the board
/Current Sensing/MUX_OUT: U23.10 (ADC1_IN0); also elsewhere on the board
/GATE_DRIVER_HI: U23.29 (TIM1_CH1); also elsewhere on the board
/GATE_DRIVER_LO: U23.30 (TIM1_CH2); also elsewhere on the board
/MCU/ADC1: U23.11 (ADC1_IN1)
/MCU/ADC2: U23.12 (ADC1_IN2)
/MCU/BOOT0: R107.2, R108.1, SW2.2, U23.44 (BOOT0)
/MCU/CC1: J3.A5 (CC1), R110.1
/MCU/CC2: J3.B5 (CC2), R109.1
/MCU/D+: J3.A6 (D+), J3.B6 (D+), R112.2, R113.2, U22.3 (I/O2), U22.4 (I/O2)
/MCU/D-: J3.A7 (D-), J3.B7 (D-), R111.2, U22.1 (I/O1), U22.6 (I/O1)
/MCU/FAN_PWM_1: Q8.1 (G), R114.1, U23.45 (TIM4_CH3)
/MCU/FAN_PWM_2: Q9.1 (G), R115.1, U23.46 (TIM4_CH4)
/MCU/PB14: U23.27 (PB14)
/MCU/PB15: U23.28 (PB15)
/MCU/POLLYFUSED: C76.1, F2.2, FB1.1
/MCU/PWM_1: M1.4 (PWM), Q8.3 (D), R116.2
/MCU/PWM_2: M2.4 (PWM), Q9.3 (D), R117.2
/MCU/RCC_OSC_IN: C73.2, U23.5 (RCC_OSC_IN), Y1.1
/MCU/RCC_OSC_OUT: C74.1, U23.6 (RCC_OSC_OUT), Y1.2
/MCU/STM_D+: R112.1, U23.33 (USB_DP)
/MCU/STM_D-: R111.1, U23.32 (USB_DM)
/MCU/SWCLK: J4.4 (SWCLK/TCK), U23.37 (SYS_JTCK-SWCLK)
/MCU/SWDIO: J4.2 (SWDIO/TMS), U23.34 (SYS_JTMS-SWDIO)
/MCU/TACHO_1: M1.3 (Tacho), U23.40 (TIM3_CH1)
/MCU/TACHO_2: M2.3 (Tacho), U23.41 (TIM3_CH2)
/MCU/TIM1_BKN: D43.1 (K), D44.1 (K), D45.1 (K), U23.16 (TIM1_BKIN)
/MCU/TIM2_CH2: U23.39 (TIM2_CH2)
/MCU/WDI: U23.31 (PA10), U24.4 (WDI)
/MCU/~MR: SW1.2, U24.3 (~MR)
/MCU/~RST: C75.2, J4.10 (~RESET), U23.7 (NRST), U24.1 (~RESET)
/PRIM_MUX_SELECT: U23.18 (PB0); also elsewhere on the board
/RCLK: U23.42 (PB6); also elsewhere on the board
/RELAY_SOFT_SWITCH: U23.19 (PB1); also elsewhere on the board
/RELAY_SWITCH: U23.20 (PB2); also elsewhere on the board
/SER: U23.21 (PB10); also elsewhere on the board
/SRCLK: U23.22 (PB11); also elsewhere on the board
/TEMP_MUX1: U23.14 (ADC1_IN4); also elsewhere on the board
/TEMP_MUX2: U23.15 (ADC1_IN5); also elsewhere on the board
/~PRIM_OCP: U23.17 (PA7); also elsewhere on the board
/~PRIM_OVP: U23.38 (PA15); also elsewhere on the board
SEC_CURRENT_SENSE: U23.13 (ADC1_IN3)
SEC_NEG_OVP: D45.2 (A), U23.26 (PB13); also elsewhere on the board
SEC_OCP: D43.2 (A), U23.2 (PC13); also elsewhere on the board
SEC_POS_OVP: D44.2 (A), U23.25 (PB12); also elsewhere on the board
SEC_SGND: C68.2, C69.2, C70.2, C71.2, C72.2, C73.1, C74.2, C75.1, C76.2, C77.2, C78.2, D42.2 (A), J3.A1 (GND), J3.A12 (GND), J3.B1 (GND), J3.B12 (GND), J3.SH (SHIELD), J4.3 (GND), J4.5 (GND), J4.9 (GNDDetect), M1.1 (-), M2.1 (-), Q8.2 (S), Q9.2 (S), R108.2, R109.2, R110.2, R114.2, R115.2, SW1.1, U22.2 (GND), U23.8 (VSSA), U23.23 (VSS), U23.35 (VSS), U23.47 (VSS), U24.2 (GND), Y1.3; also elsewhere on the board
VBUS_USB: D42.1 (K), F2.1, J3.A4 (VBUS), J3.A9 (VBUS), J3.B4 (VBUS), J3.B9 (VBUS), U22.5 (VBUS)

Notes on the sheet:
VDD PINS
+5V_SUB goes to Power sheet 3v3 LDO
SWD
Fans
Connected to pin 48
Watchdog

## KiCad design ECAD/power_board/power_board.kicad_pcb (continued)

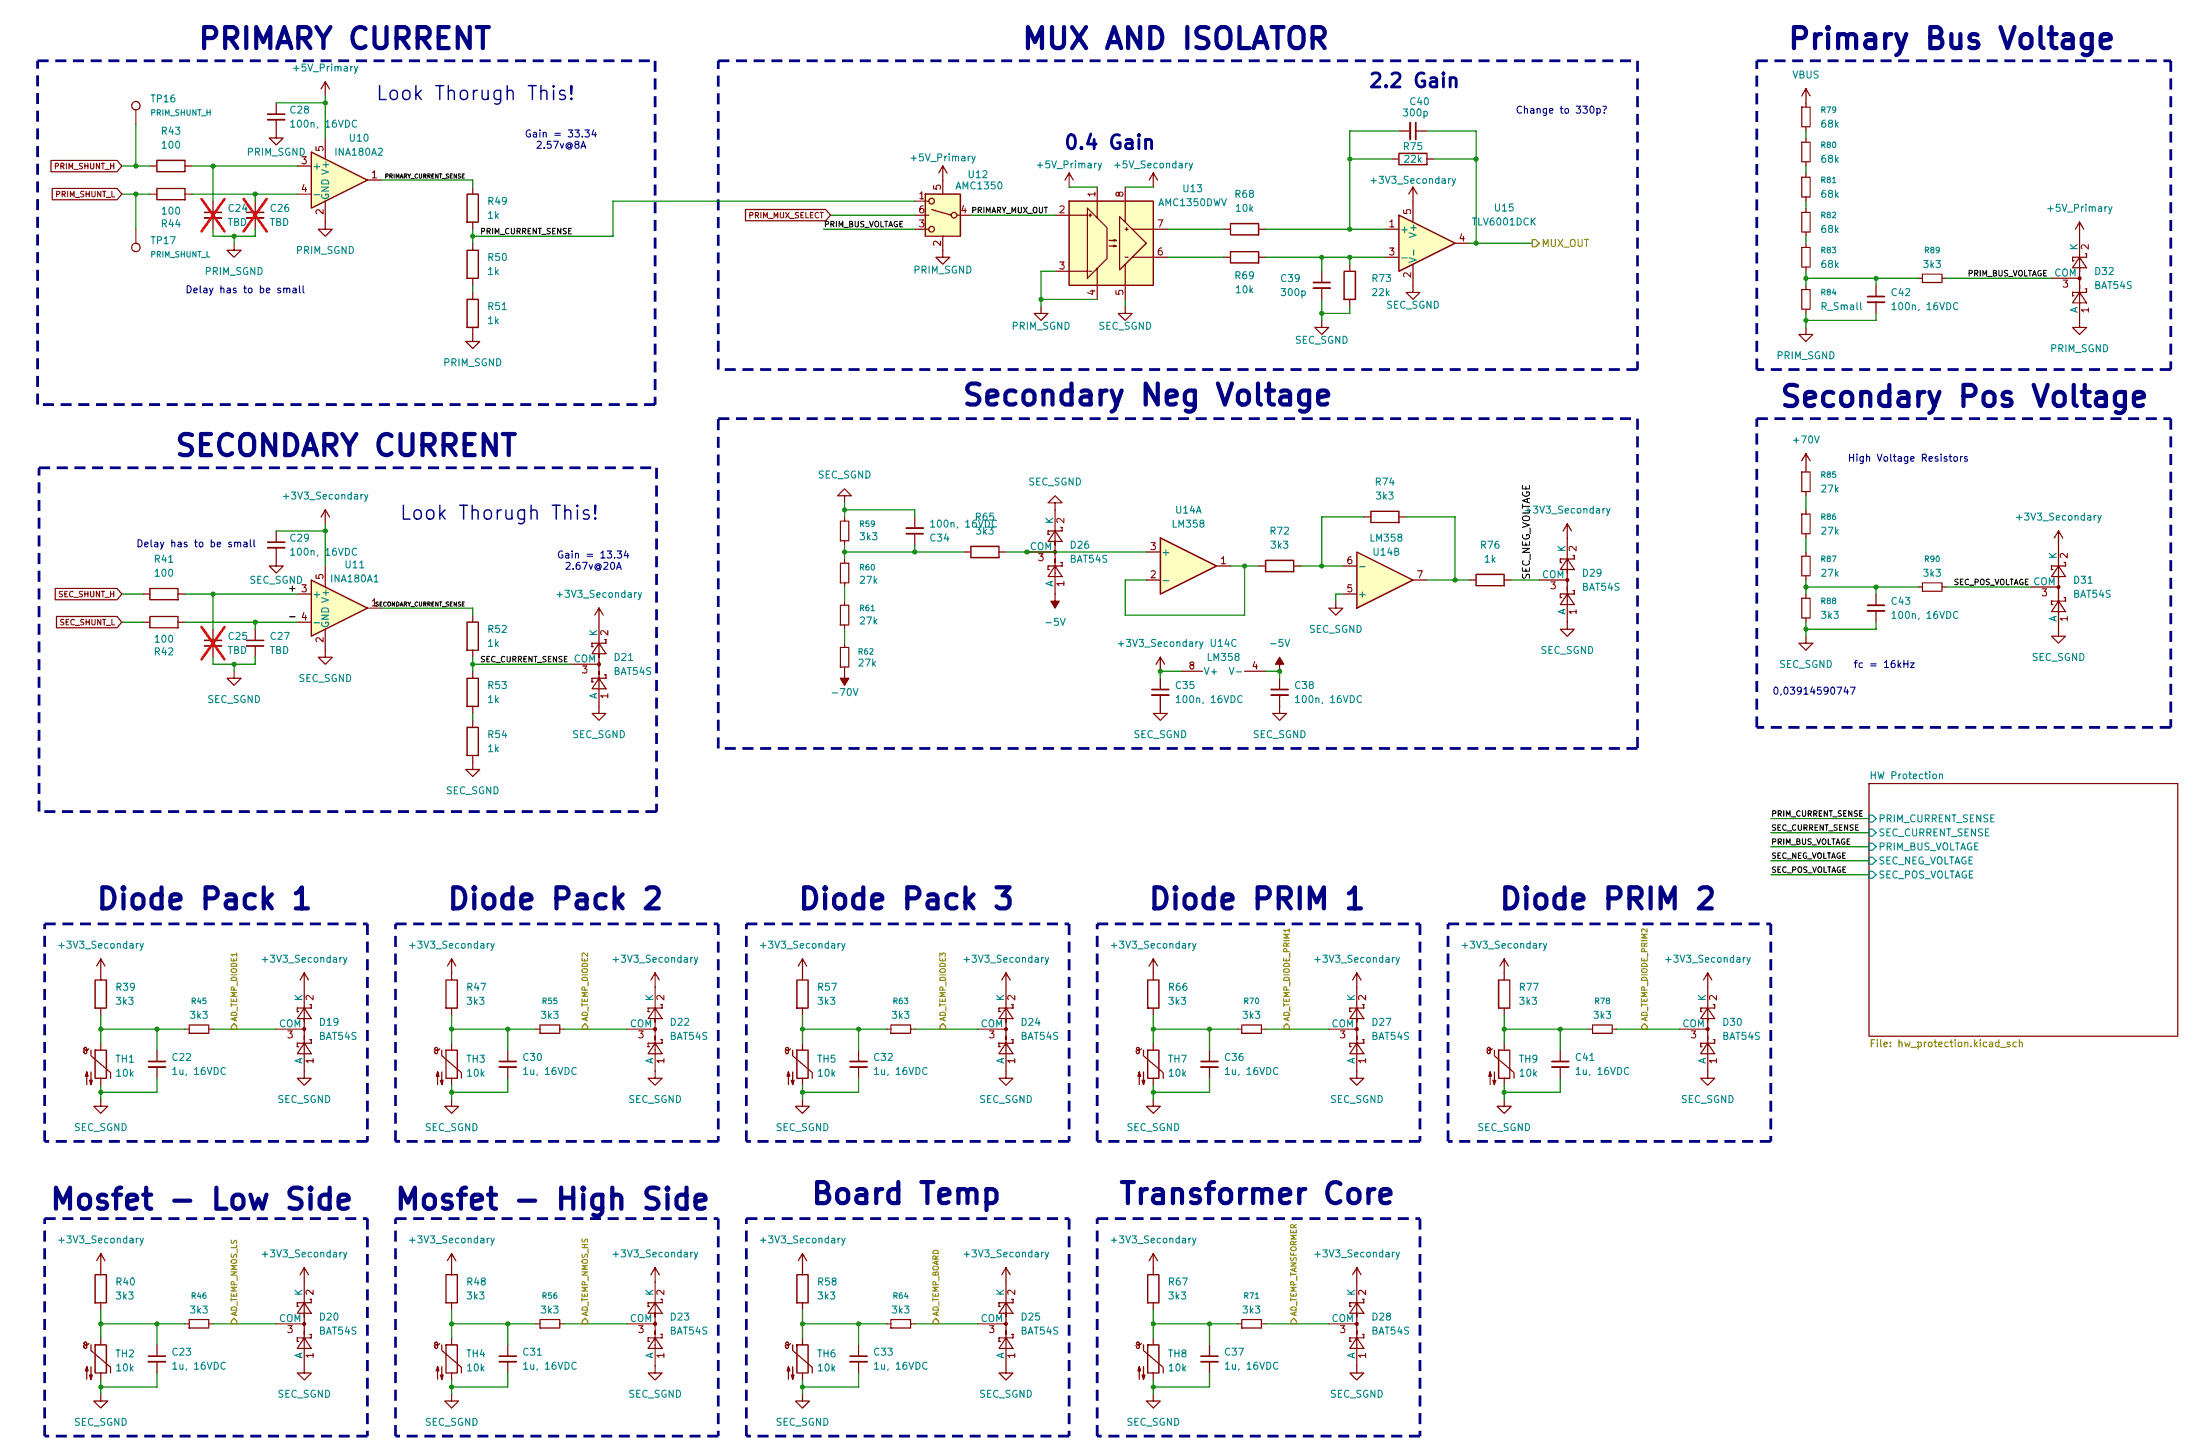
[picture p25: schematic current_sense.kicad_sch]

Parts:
C22, C23, C30, C31, C32, C33, C36, C37, C41: 1u, 16VDC; C_0805_2012Metric; Part-DB ID 36
C24, C25, C26: TBD; C_0603_1608Metric; not fitted
C27: TBD; C_0603_1608Metric
C28, C29, C34, C35, C38, C42, C43: 100n, 16VDC; C_0805_2012Metric; Part-DB ID 9
C39, C40: 300p; C_0603_1608Metric
D19, D20, D21, D22, D23, D24, D25, D26, D27, D28, D29, D30, D31, D32: BAT54S; SOT-23; Part-DB ID 92; Mouser No: 637-BAT54S
R39, R40, R45, R46, R47, R48, R55, R56, R57, R58, R59, R63, R64, R65, R66, R67, R70, R71, R72, R74, R77, R78, R88, R89, R90: 3k3; R_0603_1608Metric; Part-DB ID 72
R41, R42, R43, R44: 100; R_0805_2012Metric; Part-DB ID 28
R49, R50, R51, R52, R53, R54, R76: 1k; R_0805_2012Metric; Part-DB ID 66
R60, R61, R62, R85, R86, R87: 27k; R_0805_2012Metric
R68, R69: 10k; R_0805_2012Metric; Part-DB ID 67
R73, R75: 22k; R_0603_1608Metric
R79, R80, R81, R82, R83: 68k; R_0805_2012Metric; Part-DB ID 45
R84: R_Small; R_0603_1608Metric
TH1, TH3, TH5, TH8: 10k; PinHeader_1x02_P2.54mm_Vertical; Mouser No: 594-NTCLE350E4103GLB
TH2, TH4, TH7, TH9: 10k; PinHeader_1x02_P2.54mm_Vertical; Mouser No: 594-NTCALUG01A103JA
TH6: 10k; R_0603_1608Metric; Mouser No: 588-TX06F103F3435ER
TP16: PRIM_SHUNT_H; Pin_D0.7mm_L6.5mm_W1.8mm_FlatFork
TP17: PRIM_SHUNT_L; Pin_D0.7mm_L6.5mm_W1.8mm_FlatFork
U10: INA180A2; SOT-23-5; Mouser No: INA180A2IDBVR
U11: INA180A1; SOT-23-5; Mouser No: INA180A1IDBVR
U12: AMC1350; SOT-23-6
U13: AMC1350DWV; SOIC-8_7.5x5.85mm_P1.27mm; Mouser No: 595-AMC1350DWVR
U14: LM358; TSSOP-8_3x3mm_P0.65mm; Mouser No: 595-LM358BIPWR
U15: TLV6001DCK; SOT-353_SC-70-5

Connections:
+3V3_Secondary: C29.1, C35.1, D19.2 (K), D20.2 (K), D21.2 (K), D22.2 (K), D23.2 (K), D24.2 (K), D25.2 (K), D27.2 (K), D28.2 (K), D29.2 (K), D30.2 (K), D31.2 (K), R39.1, R40.1, R47.1, R48.1, R57.1, R58.1, R66.1, R67.1, R77.1, U11.5 (V+), U14.8 (V+), U15.5 (V+); also elsewhere on the board
+5V_Primary: C28.1, D32.2 (K), U10.5 (V+), U12.5 (S), U13.1 (VDD1); also elsewhere on the board
+5V_Secondary: U13.8 (VDD2); also elsewhere on the board
+70V: R85.1; also elsewhere on the board
-5V: C38.1, D26.1 (A), U14.4 (V-); also elsewhere on the board
-70V: R62.1; also elsewhere on the board
/Current Sensing/+: C25.1, R41.2, U11.3 (+)
/Current Sensing/-: C27.1, R42.2, U11.4 (-)
/Current Sensing/AD_TEMP_BOARD: D25.3 (COM), R64.2; also elsewhere on the board
/Current Sensing/AD_TEMP_DIODE1: D19.3 (COM), R45.2; also elsewhere on the board
/Current Sensing/AD_TEMP_DIODE2: D22.3 (COM), R55.2; also elsewhere on the board
/Current Sensing/AD_TEMP_DIODE3: D24.3 (COM), R63.2; also elsewhere on the board
/Current Sensing/AD_TEMP_DIODE_PRIM1: D27.3 (COM), R70.2; also elsewhere on the board
/Current Sensing/AD_TEMP_DIODE_PRIM2: D30.3 (COM), R78.2; also elsewhere on the board
/Current Sensing/AD_TEMP_NMOS_HS: D23.3 (COM), R56.2; also elsewhere on the board
/Current Sensing/AD_TEMP_NMOS_LS: D20.3 (COM), R46.2; also elsewhere on the board
/Current Sensing/AD_TEMP_TANSFORMER: D28.3 (COM), R71.2; also elsewhere on the board
/Current Sensing/MUX_OUT: C40.1, R75.2, U15.4; also elsewhere on the board
/Current Sensing/PRIMARY_CURRENT_SENSE: R49.1, U10.1
/Current Sensing/PRIMARY_MUX_OUT: U12.4 (A), U13.2 (IN+)
/Current Sensing/PRIM_BUS_VOLTAGE: D32.3 (COM), R89.2, U12.3 (B1); also elsewhere on the board
/Current Sensing/PRIM_CURRENT_SENSE: R49.2, R50.1, U12.1 (B2); also elsewhere on the board
/Current Sensing/SECONDARY_CURRENT_SENSE: R52.1, U11.1
/Current Sensing/SEC_CURRENT_SENSE: D21.3 (COM), R52.2, R53.1; also elsewhere on the board
/Current Sensing/SEC_NEG_VOLTAGE: D29.3 (COM), R76.2; also elsewhere on the board
/Current Sensing/SEC_POS_VOLTAGE: D31.3 (COM), R90.2; also elsewhere on the board
unnamed: C22.1, R39.2, R45.1, TH1.1
unnamed: C23.1, R40.2, R46.1, TH2.1
unnamed: C30.1, R47.2, R55.1, TH3.1
unnamed: C31.1, R48.2, R56.1, TH4.1
unnamed: C32.1, R57.2, R63.1, TH5.1
unnamed: C33.1, R58.2, R64.1, TH6.1
unnamed: C34.1, R59.1, R60.2, R65.1
unnamed: C36.1, R66.2, R70.1, TH7.1
unnamed: C37.1, R67.2, R71.1, TH8.1
unnamed: C41.1, R77.2, R78.1, TH9.1
unnamed: C42.1, R83.2, R84.1, R89.1
unnamed: C43.1, R87.2, R88.1, R90.1
unnamed: D26.3 (COM), R65.2, U14.3 (+)
unnamed: R50.2, R51.1
unnamed: R53.2, R54.1
unnamed: R60.1, R61.2
unnamed: R61.1, R62.2
unnamed: R74.2, R76.1, U14.7
unnamed: R79.2, R80.1
unnamed: R80.2, R81.1
unnamed: R81.2, R82.1
unnamed: R82.2, R83.1
unnamed: R85.2, R86.1
unnamed: R86.2, R87.1
unnamed: C24.1, R43.2, U10.3 (+)
unnamed: C26.1, R44.2, U10.4 (-)
unnamed: R68.1, U13.7 (OUT+)
unnamed: R69.1, U13.6 (OUT-)
unnamed: R72.1, U14.1, U14.2 (-)
unnamed: R72.2, R74.1, U14.6 (-)
unnamed: C40.2, R68.2, R75.1, U15.1 (+)
unnamed: C39.1, R69.2, R73.1, U15.3 (-)
PRIM_MUX_SELECT: U12.6 (S)
PRIM_SGND: C24.2, C26.2, C28.2, C42.2, D32.1 (A), R51.2, R84.2, U10.2 (GND), U12.2 (GND), U13.3 (IN-), U13.4 (GND1); also elsewhere on the board
PRIM_SHUNT_H: R43.1, TP16.1 (1_1); also elsewhere on the board
PRIM_SHUNT_L: R44.1, TP17.1 (1_1); also elsewhere on the board
SEC_SGND: C22.2, C23.2, C25.2, C27.2, C29.2, C30.2, C31.2, C32.2, C33.2, C34.2, C35.2, C36.2, C37.2, C38.2, C39.2, C41.2, C43.2, D19.1 (A), D20.1 (A), D21.1 (A), D22.1 (A), D23.1 (A), D24.1 (A), D25.1 (A), D26.2 (K), D27.1 (A), D28.1 (A), D29.1 (A), D30.1 (A), D31.1 (A), R54.2, R59.2, R73.2, R88.2, TH1.2, TH2.2, TH3.2, TH4.2, TH5.2, TH6.2, TH7.2, TH8.2, TH9.2, U11.2 (GND), U13.5 (GND2), U14.5 (+), U15.2 (V-); also elsewhere on the board
SEC_SHUNT_H: R41.1; also elsewhere on the board
SEC_SHUNT_L: R42.1; also elsewhere on the board
VBUS: R79.1; also elsewhere on the board

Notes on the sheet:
Diode Pack 3
Transformer Core
Board Temp
Gain = 13.34 2.67v@20A
2.2 Gain
Change to 330p?
Mosfet - Low Side
Delay has to be small
Look Thorugh This!
PRIMARY CURRENT
0,03914590747
High Voltage Resistors
Diode PRIM 1
Diode PRIM 2
MUX AND ISOLATOR
fc = 16kHz
Secondary Neg Voltage
0.4 Gain
Primary Bus Voltage
Secondary Pos Voltage
Diode Pack 1
Diode Pack 2
Mosfet - High Side
Gain = 33.34 2.57v@8A
SECONDARY CURRENT

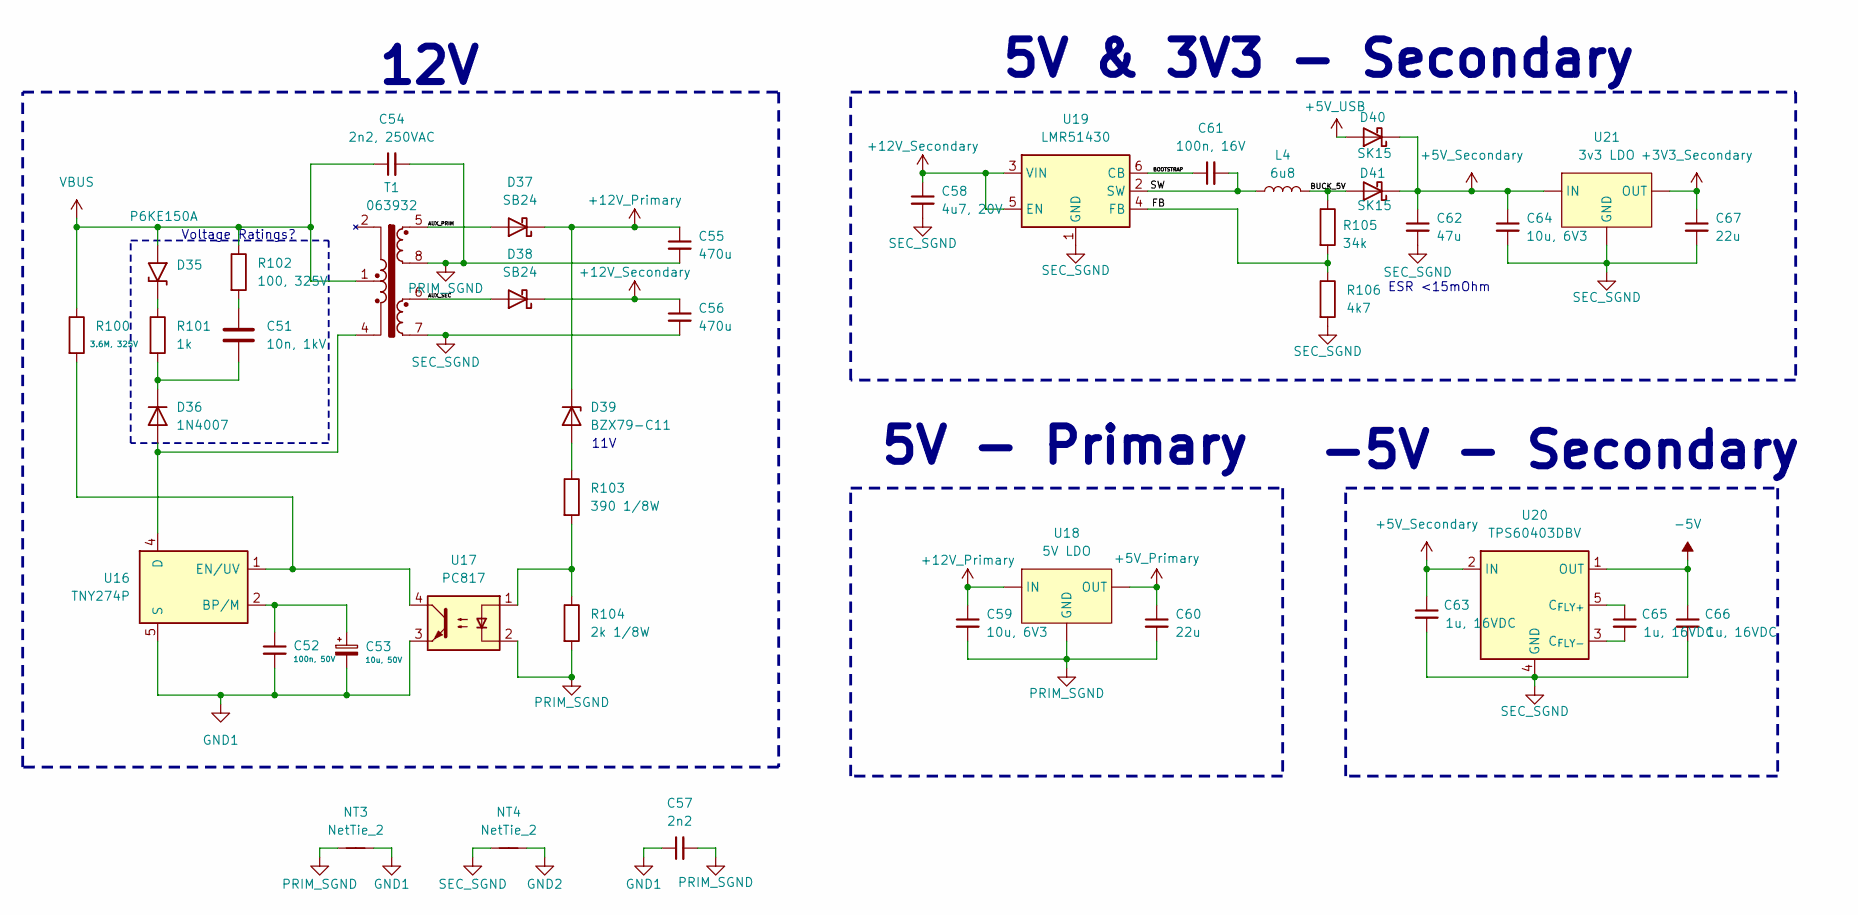
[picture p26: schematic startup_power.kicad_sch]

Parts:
C51: 10n, 1kV; C_1206_3216Metric; Mouser No: 791-1206B103M102CT
C52: 100n, 50V; C_0805_2012Metric; Part-DB ID 25; Mouser No: 603-CC603KRX5R9BB104
C53: 10u, 50V; CP_Radial_D5.0mm_P2.00mm; Mouser No: 710-860020672010
C54: 2n2, 250VAC; C_Rect_L18.0mm_W6.0mm_P15.00mm_FKS3_FKP3; Mouser No: 594-F340Y232230MFP2B
C55, C56: 470u; C_Radial_D10.0mm_H16.0mm_P5.00mm
C57: 2n2; C_Rect_L18.0mm_W6.0mm_P15.00mm_FKS3_FKP3; Mouser No: 594-F340Y232230MFP2B
C58: 4u7, 20V; C_0805_2012Metric; Mouser No: 791-0805X475M250CT
C59, C64: 10u, 6V3; C_0805_2012Metric; Part-DB ID 6
C60, C67: 22u; C_0805_2012Metric; Part-DB ID 5
C61: 100n, 16V; C_0805_2012Metric
C62: 47u; C_1206_3216Metric
C63, C65, C66: 1u, 16VDC; C_0805_2012Metric; Part-DB ID 36
D35: P6KE150A; D_DO-15_P10.16mm_Horizontal; Mouser No: 576-P6KE150A
D36: 1N4007; D_DO-41_SOD81_P10.16mm_Horizontal
D37, D38: SB24; D_SOD-128; Mouser No: 241-SB24AFCAUR1000A1
D39: BZX79-C11; D_DO-35_SOD27_P7.62mm_Horizontal; Mouser No: 512-BZX79C11
D40, D41: SK15; D_SMA_Handsoldering
L4: 6u8; Inductor_SMD_Pulse_BPSC_10.5x10.3mm; Mouser No: 603-BPSC1011406R8M00
NT3, NT4: NetTie_2
R100: 3.6M, 325V; R_Axial_DIN0309_L9.0mm_D3.2mm_P12.70mm_Horizontal; Mouser No: 603-CFR-50JB-52-3M6
R101: 1k; R_0805_2012Metric; Part-DB ID 66
R102: 100, 325V; R_Axial_DIN0411_L9.9mm_D3.6mm_P12.70mm_Horizontal; Mouser No: 708-RSMF1JT100R
R103: 390 1/8W; R_0805_2012Metric
R104: 2k 1/8W; R_0805_2012Metric
R105: 34k; R_0603_1608Metric
R106: 4k7; R_0805_2012Metric
T1: 063932; Mouser Part Number 652-63932
U16: TNY274P; PowerIntegrations_PDIP-8C; Mouser No: 869-TNY274PN
U17: PC817; SOP-4_4.4x2.6mm_P1.27mm; Mouser No: 852-PC817X1CSP9F
U18: 5V LDO; SOT-223-3_TabPin2; Mouser No: 621-AZ1117CH2-5.0TRG
U19: LMR51430; SOT-23-6
U20: TPS60403DBV; SOT-23-5; Part-DB ID 48
U21: 3v3 LDO; SOT-223-3_TabPin2; Mouser No: 621-AZ1117CH2-33TRG1

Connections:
+3V3_Secondary: C67.1, U21.3 (OUT); also elsewhere on the board
+5V_Primary: C60.1, U18.3 (OUT); also elsewhere on the board
+5V_Secondary: C62.1, C63.1, C64.1, D40.1 (K), D41.1 (K), U20.2 (IN), U21.1 (IN); also elsewhere on the board
+5V_USB: D40.2 (A); also elsewhere on the board
+12V_Primary: C55.1, C59.1, D37.1 (K), D39.1 (K), U18.1 (IN); also elsewhere on the board
+12V_Secondary: C56.1, C58.1, D38.1 (K), U19.3 (VIN), U19.5 (EN); also elsewhere on the board
-5V: C66.1, U20.1 (OUT); also elsewhere on the board
/Startup Power/AUX_PRIM: D37.2 (A), T1.5
/Startup Power/AUX_SEC: D38.2 (A), T1.6
/Startup Power/BOOTSTRAP: C61.1, U19.6 (CB)
/Startup Power/BUCK_5V: D41.2 (A), L4.2, R105.1
/Startup Power/FB: R105.2, R106.1, U19.4 (FB)
/Startup Power/SW: C61.2, L4.1, U19.2 (SW)
GND1: C52.2, C53.2, C57.1, NT3.2, U16.5 (S), U16.6 (S), U16.7 (S), U16.8 (S), U17.3; also elsewhere on the board
unnamed: C51.1, R102.2
unnamed: D35.2, R101.1
unnamed: D36.2 (A), T1.4, U16.4 (D)
unnamed: C51.2, D36.1 (K), R101.2
unnamed: D39.2 (A), R103.1
unnamed: R103.2, R104.1, U17.1
unnamed: C52.1, C53.1, U16.2 (BP/M)
unnamed: R100.2, U16.1 (EN/UV), U17.4
unnamed: C65.1, U20.5 (C_{FLY+})
unnamed: C65.2, U20.3 (C_{FLY-})
PRIM_SGND: C54.2, C55.2, C57.2, C59.2, C60.2, NT3.1, R104.2, T1.8, U17.2, U18.2 (GND); also elsewhere on the board
SEC_SGND: C56.2, C58.2, C62.2, C63.2, C64.2, C66.2, C67.2, NT4.1, R106.2, T1.7, U19.1 (GND), U20.4 (GND), U21.2 (GND); also elsewhere on the board
VBUS: C54.1, D35.1, R100.1, R102.1, T1.1; also elsewhere on the board

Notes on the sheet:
5V - Primary
11V
ESR <15mOhm
5V & 3V3 - Secondary
-5V - Secondary
Voltage Ratings?
12V

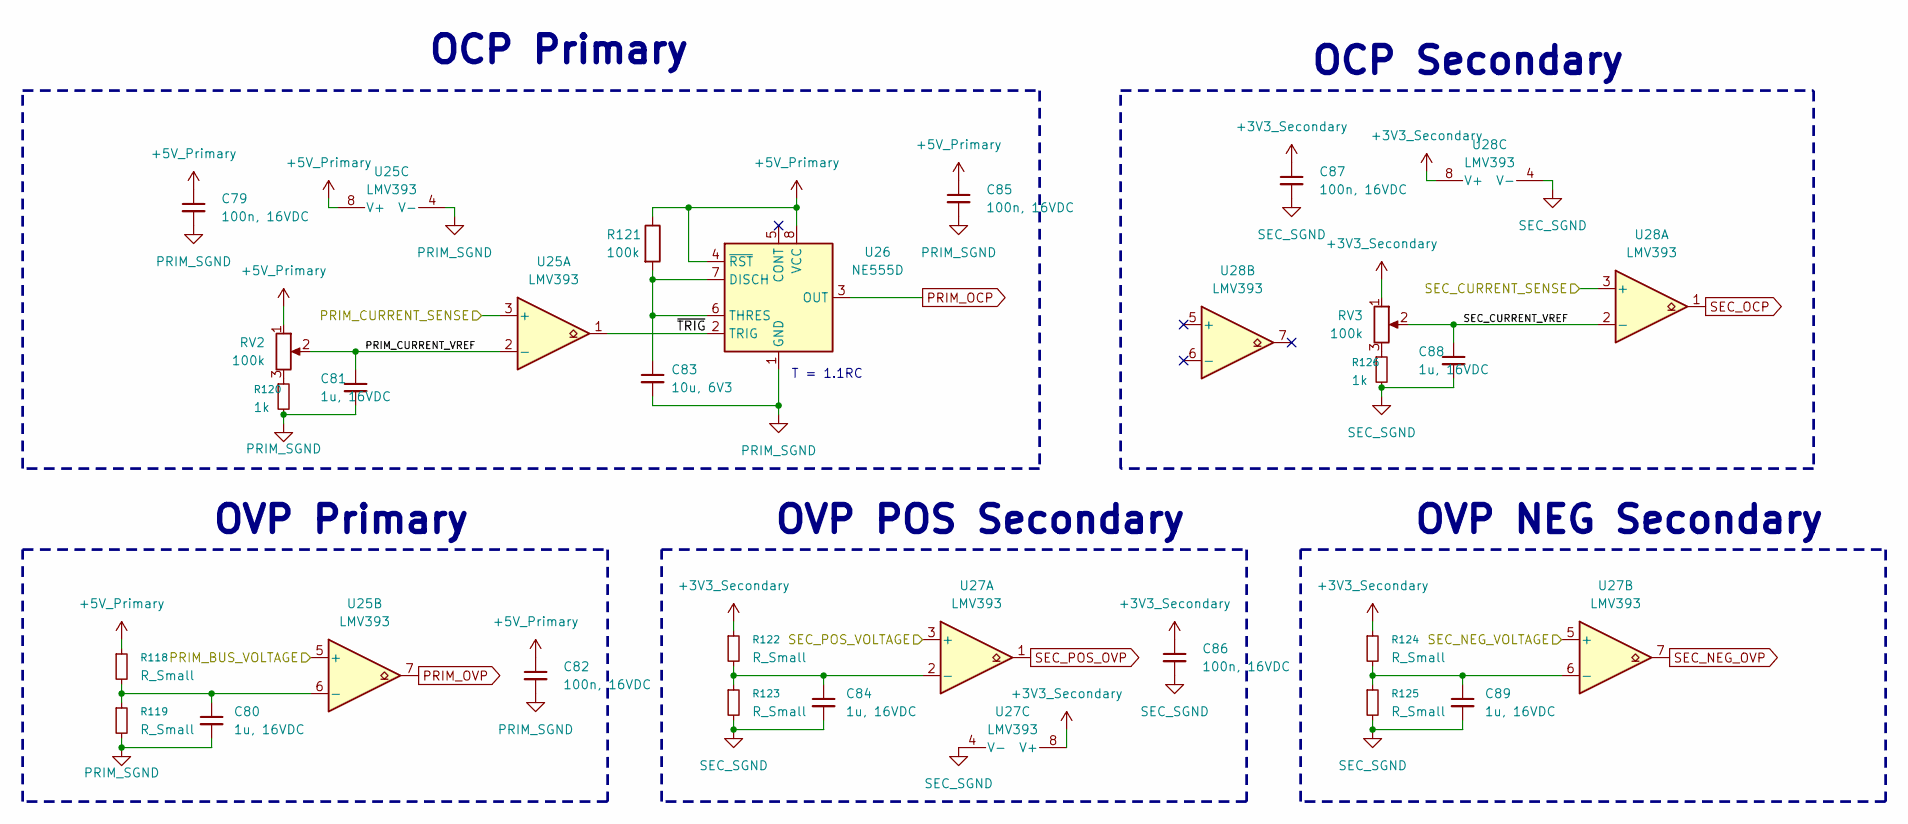
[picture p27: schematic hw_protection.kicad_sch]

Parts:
C79, C82, C85, C86, C87: 100n, 16VDC; C_0805_2012Metric; Part-DB ID 9
C80, C81, C84, C88, C89: 1u, 16VDC; C_0805_2012Metric; Part-DB ID 36
C83: 10u, 6V3; C_0805_2012Metric; Part-DB ID 6
R118, R119, R122, R123, R124, R125: R_Small; R_0603_1608Metric
R120, R126: 1k; R_0805_2012Metric; Part-DB ID 66
R121: 100k; R_0805_2012Metric
RV2, RV3: 100k; Potentiometer_SMD_Trimmer_PVG3_3.6x3
U25: LMV393; SOIC-8_3.9x4.9mm_P1.27mm; Mouser No: 511-LMV393IDT
U26: NE555D; SOIC-8_3.9x4.9mm_P1.27mm
U27, U28: LMV393

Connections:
+3V3_Secondary: C86.1, C87.1, R122.1, R124.1, RV3.1, U27.8 (V+), U28.8 (V+); also elsewhere on the board
+5V_Primary: C79.1, C82.1, C85.1, R118.1, R121.1, RV2.1, U25.8 (V+), U26.4 (~RST), U26.8 (VCC); also elsewhere on the board
/Current Sensing/HW Protection/PRIM_CURRENT_VREF: C81.1, RV2.2, U25.2 (-)
/Current Sensing/HW Protection/SEC_CURRENT_VREF: C88.1, RV3.2, U28.2 (-)
/Current Sensing/HW Protection/~TRIG: U25.1, U26.2 (TRIG)
/Current Sensing/PRIM_BUS_VOLTAGE: U25.5 (+); also elsewhere on the board
/Current Sensing/PRIM_CURRENT_SENSE: U25.3 (+); also elsewhere on the board
/Current Sensing/SEC_CURRENT_SENSE: U28.3 (+); also elsewhere on the board
/Current Sensing/SEC_NEG_VOLTAGE: U27.5 (+); also elsewhere on the board
/Current Sensing/SEC_POS_VOLTAGE: U27.3 (+); also elsewhere on the board
unnamed: R120.1, RV2.3
unnamed: R126.1, RV3.3
unnamed: C80.1, R118.2, R119.1, U25.6 (-)
unnamed: C83.1, R121.2, U26.6 (THRES), U26.7 (DISCH)
unnamed: C84.1, R122.2, R123.1, U27.2 (-)
unnamed: C89.1, R124.2, R125.1, U27.6 (-)
PRIM_OCP: U26.3 (OUT); also elsewhere on the board
PRIM_OVP: U25.7; also elsewhere on the board
PRIM_SGND: C79.2, C80.2, C81.2, C82.2, C83.2, C85.2, R119.2, R120.2, U25.4 (V-), U26.1 (GND); also elsewhere on the board
SEC_NEG_OVP: U27.7; also elsewhere on the board
SEC_OCP: U28.1; also elsewhere on the board
SEC_POS_OVP: U27.1; also elsewhere on the board
SEC_SGND: C84.2, C86.2, C87.2, C88.2, C89.2, R123.2, R125.2, R126.2, U27.4 (V-), U28.4 (V-); also elsewhere on the board

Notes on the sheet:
OCP Primary
OVP POS Secondary
OVP NEG Secondary
OCP Secondary
T = 1.1RC
OVP Primary

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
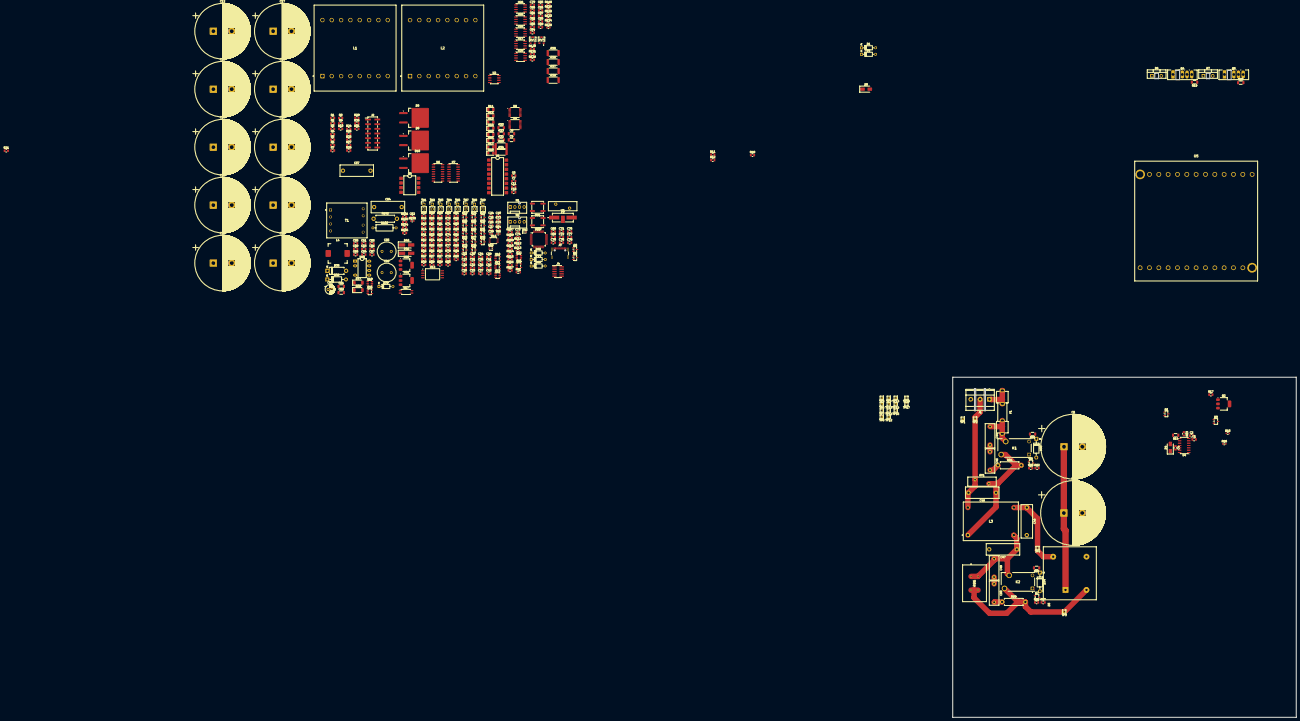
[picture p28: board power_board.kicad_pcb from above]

Board: 4 copper layers, 346 parts (0 on the bottom side), 217 nets.

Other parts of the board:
U25#2: LMV393; SOIC-8_3.9x4.9mm_P1.27mm

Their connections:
+5V_Primary: U25#2.8 (V+); also elsewhere on the board
/Current Sensing/PRIM_BUS_VOLTAGE: U25#2.3 (+); also elsewhere on the board
PRIM_OVP: U25#2.1; also elsewhere on the board
PRIM_SHUNT_L: U25#2.4 (V-); also elsewhere on the board

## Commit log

2026-04-16 First rough sketch
    [power_board.kicad_pcb, power_board.kicad_sch]
2026-07-15 Fundemental function down
    [ac_input_filter.kicad_sch, current_sense.kicad_sch, mcu.kicad_sch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]
2026-07-18 Assign footprints
    [ac_input_filter.kicad_sch, current_sense.kicad_sch, mcu.kicad_sch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]
2026-09-18 Before PR
    [ac_input_filter.kicad_sch, current_sense.kicad_sch, hw_protection.kicad_sch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]
2026-09-20 Changed file structure
    [063932.stp, 10_segment_bar_graph.step, 6.3mm_female_2-pol_mono_PCB.stp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]
